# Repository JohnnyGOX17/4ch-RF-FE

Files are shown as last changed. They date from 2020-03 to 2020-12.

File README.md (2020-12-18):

# 4-Channel RF Front End

An open-source (KiCAD) RF front end with 4 independent RX &amp; TX channels optimized for MIMO/Radar prototyping. It implements an I2C bus for digital control of each channel’s attenuation and single-ended control of T/R switch for fast action. A switch-mode power supply and separate low dropout regulators for each channel are utilized to provide low-ripple power to RF Low Noise Amplifiers.

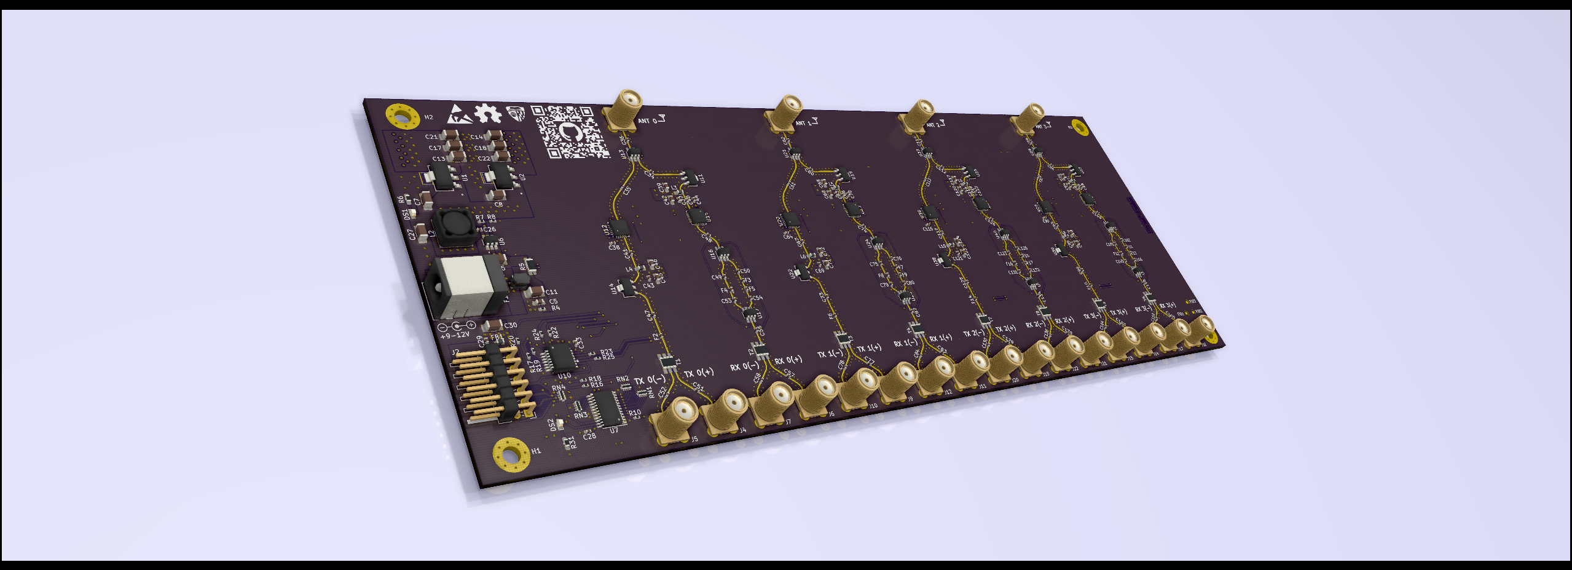
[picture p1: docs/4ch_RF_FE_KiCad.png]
kicad 3D


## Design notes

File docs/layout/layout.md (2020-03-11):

# Layout Notes

## [OSH-Park 4-Layer Prototype Service](https://docs.oshpark.com/services/four-layer/)

### Logistics

* Nominally shipped within 12 days of ordering
* >100 square inches of board space can be done with [Medium Run Service](https://docs.oshpark.com/services/four-layer-medium-run/)

### [KiCad Layout Settings](https://docs.oshpark.com/design-tools/kicad/kicad-design-rules/)

* Use Imperial (mils) units when inputting
* `Solder Mask Clearance` = 2 mil
* `Solder Mask Min Width` = 4 mil
* Disable both `blind/buried vias` and `micro vias`
* `Min track width` = 5 mil
* `Min track clearance` = 5 mil
* `Min via drill diameter` = 10 mil
* `Min via diameter` = 18 mil
  + Calculated as `(min drill diameter) + (annular ring spec)*2`
  + `Minimum Annular Ring` = 4 mil

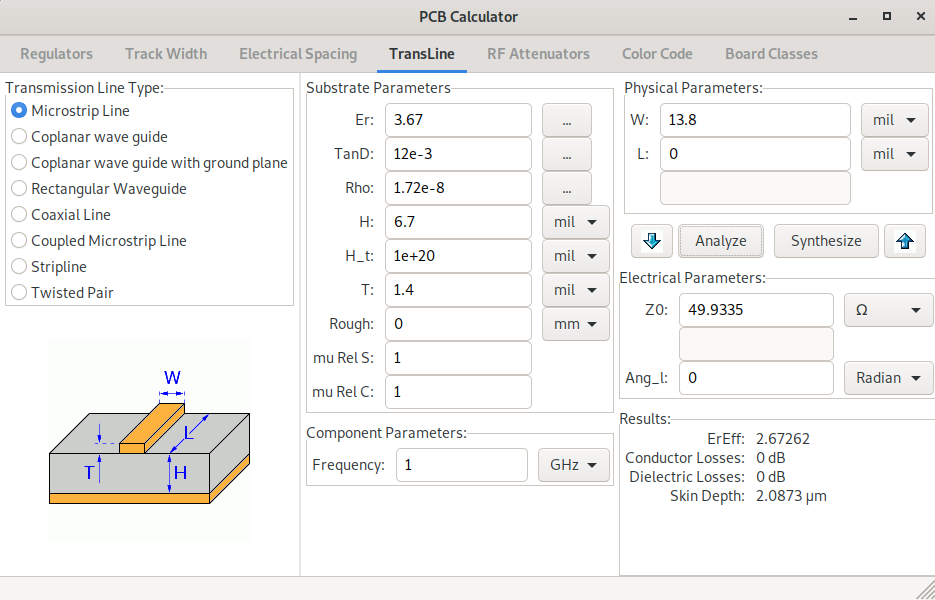
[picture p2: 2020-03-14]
docs/layout/50Ohm_SE_microstrip.png

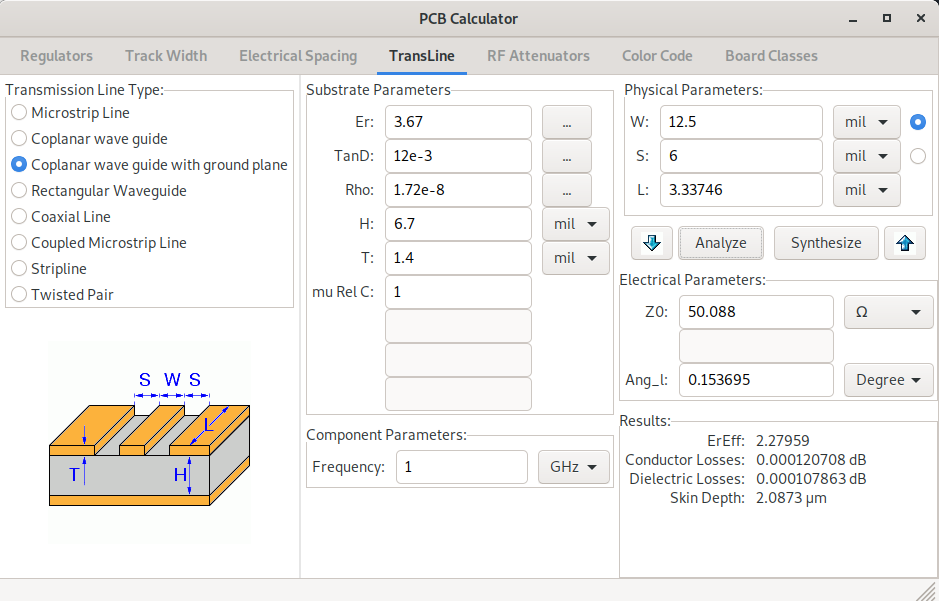
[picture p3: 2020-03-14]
docs/layout/50Ohm_CPWG_GND_plane.png

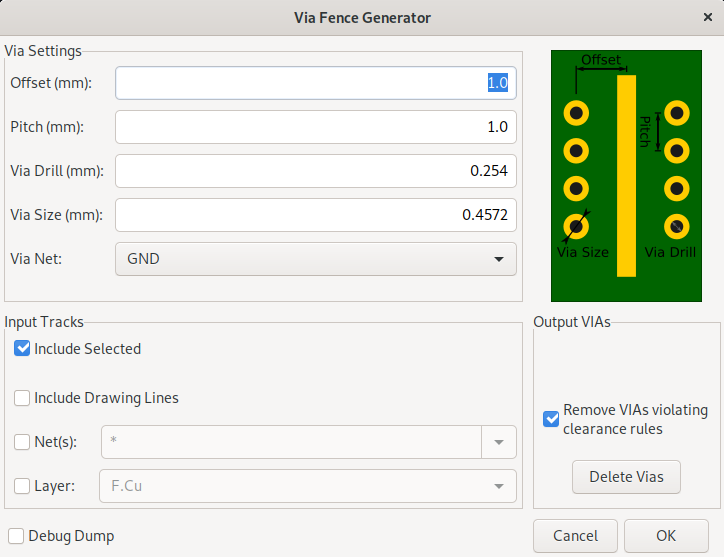
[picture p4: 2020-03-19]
docs/layout/CPWG_via_stitching.png

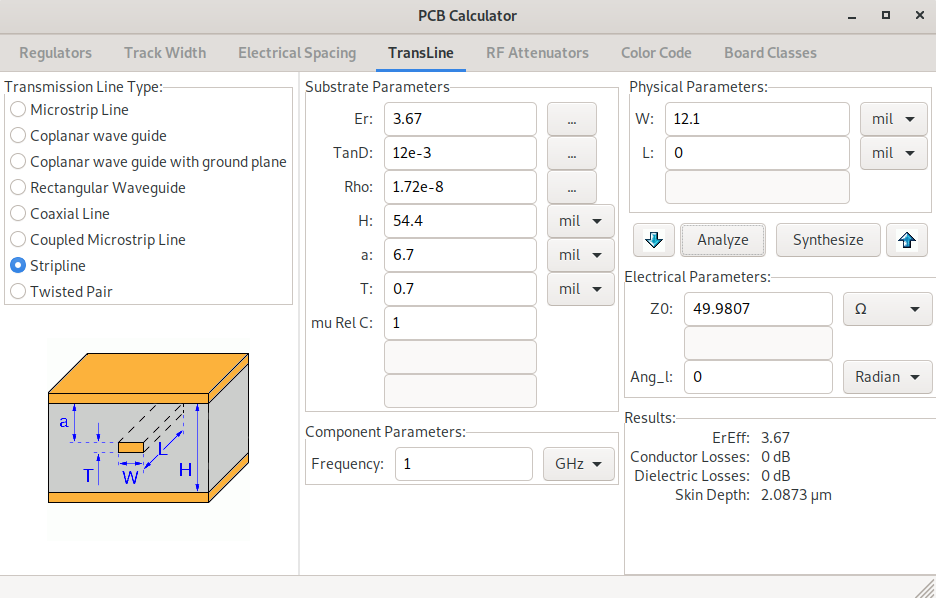
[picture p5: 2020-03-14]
docs/layout/50Ohm_SE_Stripline.png

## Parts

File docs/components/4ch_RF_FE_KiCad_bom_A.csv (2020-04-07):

Component | Description | Part | References | Value | Footprint | Quantity Per PCB | Datasheet | Digi-Key PN | Category | DK_Datasheet_Link | DK_Detail_Page | Family | MPN | Manufacturer | Status
1 | Unpolarized capacitor | C | C1 C4 C12 C26 C28 C29 C31 C32 C33 C38 C44 C55 C59 C64 C70 C81 C85 C90 C96 C107 C111 C116 C122 C133 C137 | 0.1µF | C_0402_1005Metric | 25 | https://search.murata.co.jp/Ceramy/image/img/A01X/G101/ENG/GRM155R71H104KE14-01.pdf | 490-13342-1-ND
2 | Unpolarized capacitor | C | C39 C45 C65 C71 C91 C97 C117 C123 | 1.2nF | C_0603_1608Metric_Pad1.05x0.95mm_HandSolder | 8 | https://api.kemet.com/component-edge/download/datasheet/C0603C122K5RACTU.pdf | 399-7851-1-ND
3 | Unpolarized capacitor | C | C7 C8 C9 C10 C11 C13 C14 C15 C16 C17 C18 C19 C20 C21 C22 C23 C24 C25 C30 | 10µF | C_1206_3216Metric_Pad1.42x1.75mm_HandSolder | 19 | http://www.samsungsem.com/kr/support/product-search/mlcc/CL31B106KAHNNNE.jsp | 1276-1804-1-ND
4 | Unpolarized capacitor | C | C3 C5 C6 C42 C46 C68 C72 C94 C98 C120 C124 | 1µF | C_0603_1608Metric_Pad1.05x0.95mm_HandSolder | 11 | http://www.samsungsem.com/kr/support/product-search/mlcc/CL10B105KA8NFNC.jsp | 1276-1942-1-ND
5 | Unpolarized capacitor | C | C27 | 22µF | C_1206_3216Metric_Pad1.42x1.75mm_HandSolder | 1 | http://www.samsungsem.com/kr/support/product-search/mlcc/CL31B226KQHNNNE.jsp | 1276-3146-1-ND
6 | Unpolarized capacitor | C | C34 C35 C36 C40 C41 C47 C48 C49 C50 C51 C52 C53 C54 C56 C57 C58 C60 C61 C62 C66 C67 C73 C74 C75 C76 C77 C78 C79 C80 C82 C83 C84 C86 C87 C88 C92 C93 C99 C100 C101 C102 C103 C104 C105 C106 C108 C109 C110 C112 C113 C114 C118 C119 C125 C126 C127 C128 C129 C130 C131 C132 C134 C135 C136 | 330pF | C_0402_1005Metric | 64 | https://api.kemet.com/component-edge/download/datasheet/C0402C331J5GACTU.pdf | 399-7787-1-ND
7 | Unpolarized capacitor | C | C37 C43 C63 C69 C89 C95 C115 C121 | 68pF | C_0402_1005Metric | 8 | https://api.kemet.com/component-edge/download/datasheet/C0402C680K5RAC7867.pdf | 399-19382-1-ND
8 | LED GREEN CLEAR CHIP SMD | LTST-C190KGKT | DS1 DS2 | LTST-C190KGKT | LED_0603 | 2 | http://optoelectronics.liteon.com/upload/download/DS22-2000-074/LTST-C190KGKT.PDF | 160-1435-1-ND | Optoelectronics | http://optoelectronics.liteon.com/upload/download/DS22-2000-074/LTST-C190KGKT.PDF | /product-detail/en/lite-on-inc/LTST-C190KGKT/160-1435-1-ND/386814 | LED Indication - Discrete | LTST-C190KGKT | Lite-On Inc. | Active
9 | RF FILTER HIGH PASS 2.4GHZ 0603 | DEA162300HT-8047A1 | F5 F9 F13 F17 | DEA162300HT-8047A1 | F_DEA16_LGA | 4 | https://media.digikey.com/pdf/Data%20Sheets/TDK%20PDFs/DEA162300HT-8047A1_Rev1_0.pdf | 445-175383-1-ND |  |  |  |  |  | TDK
10 | FUSE BOARD MOUNT 5A 32VDC 0603 | ERB-RE5R00V | F1 | ERB-RE5R00V | 603 | 1 | https://industrial.panasonic.com/cdbs/www-data/pdf/AFA0000/AFA0000C7.pdf | P15125CT-ND | Circuit Protection |  |  | Fuses |  | Panasonic | Active
11 | DC to 2.14 GHz 50 Ohm Low Pass Filter | LP0603A2140ANTR | F4 F8 F12 F16 | LP0603A2140ANTR | F_0603_2x2_LGA | 4 | http://datasheets.avx.com/lp0603.pdf | 478-2914-1-ND |  |  |  |  |  | AVX
12 | DC to 3600 MHz 50 Ohm Low Pass Filter | LPF04023600L | F2 F3 F6 F7 F10 F11 F14 F15 | LPF04023600L | F_0402_1005Metric_2x2_LGA | 8 | https://media.digikey.com/pdf/Data%20Sheets/American%20Technical%20Ceramics/0402_LPF_Series_DS.pdf | 1284-1984-1-ND |  |  |  |  |  | ATC
13 | FERRITE BEAD 1.5 KOHM 0603 1LN | BLM18HE152SN1D | FB1 | BLM18HE152SN1D | 603 | 1 | https://www.murata.com/en-us/products/productdata/8796741599262/ENFA0004.pdf | 490-5216-1-ND | Filters | https://www.murata.com/en-us/products/productdata/8796741599262/ENFA0004.pdf | /product-detail/en/murata-electronics-north-america/BLM18HE152SN1D/490-5216-1-ND/1948392 | Ferrite Beads and Chips | BLM18HE152SN1D | Murata Electronics North America | Active
14 | CONN SMA JACK STR 50 OHM PCB | 5-1814832-1 | J3 J4 J5 J6 J7 J8 J9 J10 J11 J12 J13 J14 J15 J16 J17 J18 J19 J20 J21 J22 | 5-1814832-1 | RF_SMA_Vertical_5-1814832-1 | 20 | https://www.te.com/commerce/DocumentDelivery/DDEController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 | A97594-ND | Connectors, Interconnects | https://www.te.com/commerce/DocumentDelivery/DDEController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 | /product-detail/en/te-connectivity-amp-connectors/5-1814832-1/A97594-ND/1755982 | Coaxial Connectors (RF) | 5-1814832-1 | TE Connectivity AMP Connectors | Active
15 | CONN PWR JACK 1.75X4.75MM SOLDER | PJ1-021-SMT-TR | J1 | PJ1-021-SMT-TR | CUI_PJ1-021-SMT-TR | 1 | https://www.cuidevices.com/product/resource/pj1-021-smt-tr.pdf | CP1-021PJCT-ND
16 | CONN HDR 12POS 0.1 TIN PCB R/A | PPTC062LJBN-RC | J2 | PPTC062LJBN-RC | PinHeader_2x06_P2.54mm_Horizontal | 1 | https://media.digikey.com/pdf/Data%20Sheets/Sullins%20PDFs/Female_Headers.100_DS.pdf | S5520-ND | Connectors, Interconnects |  |  | Rectangular Connectors - Headers, Female Pins |  | Sullins Connector Solutions | Active
17 | Inductor | L | L3 L4 L5 L6 L7 L8 L9 L10 | 43nH | L_0603_1608Metric_Pad1.05x0.95mm_HandSolder | 8 | https://search.murata.co.jp/Ceramy/image/img/P02/JELF243A-0024.pdf | 490-6892-1-ND
18 | CMC 500 Ohms @ 100MHz 2A DCR 40 mOhm | ACP3225 | L1 | ACP3225 | CMC_3225_2x2_LGA | 1 | https://product.tdk.com/info/en/catalog/datasheets/cmf_commercial_power_acp3225_en.pdf | 445-172408-1-ND
19 | FIXED IND 3.3UH 3.5A 20 MOHM SMD | SRR6038-3R3Y | L2 | SRR6038-3R3Y | SRR6038-3R3Y | 1 | https://www.bourns.com/docs/Product-Datasheets/SRR6038.pdf | SRR6038-3R3YCT-ND
20 | Resistor, US symbol | R_US | R2 R3 | 10 | R_0402_1005Metric | 2 | https://www.yageo.com/upload/media/product/productsearch/datasheet/rchip/PYu-RC_Group_51_RoHS_L_10.pdf | 311-10.0LRCT-ND
21 | Resistor, US symbol | R_US | R23 R25 | 100 | R_0402_1005Metric | 2 | https://www.yageo.com/upload/media/product/productsearch/datasheet/rchip/PYu-RC_Group_51_RoHS_L_10.pdf | 311-100LRCT-ND
22 | Resistor, US symbol | R_US | R4 | 100k | R_0402_1005Metric | 1 | https://www.yageo.com/upload/media/product/productsearch/datasheet/rchip/PYu-RC_Group_51_RoHS_L_10.pdf | 311-100KLRCT-ND
23 | Resistor, US symbol | R_US | R8 R10 R11 R12 R14 R26 R27 R28 R29 R30 | 10k | R_0402_1005Metric | 10 | https://www.yageo.com/upload/media/product/productsearch/datasheet/rchip/PYu-RC_Group_51_RoHS_L_10.pdf | 311-10.0KLRCT-ND
24 | Resistor, US symbol | R_US | R6 | 180 | R_0603_1608Metric_Pad1.05x0.95mm_HandSolder | 1 | https://www.yageo.com/upload/media/product/productsearch/datasheet/rchip/PYu-RC_Group_51_RoHS_L_10.pdf | 311-180GRCT-ND
25 | Resistor, US symbol | R_US | R16 R17 R18 R19 R20 R21 R22 R24 | 33 | R_0402_1005Metric | 8 | https://www.yageo.com/upload/media/product/productsearch/datasheet/rchip/PYu-RC_Group_51_RoHS_L_10.pdf | 311-33.0LRCT-ND
26 | Resistor, US symbol | R_US | R7 | 61.9k | R_0402_1005Metric | 1 | https://www.yageo.com/upload/media/product/productsearch/datasheet/rchip/PYu-RC_Group_51_RoHS_L_10.pdf | 311-61.9KLRCT-ND
27 | Resistor, US symbol | R_US | R31 | 75 | R_0603_1608Metric_Pad1.05x0.95mm_HandSolder | 1 | https://www.yageo.com/upload/media/product/productsearch/datasheet/rchip/PYu-RC_Group_51_RoHS_L_10.pdf | 311-75.0HRCT-ND
28 | RES 0.002 OHM 1% 1W 1206 | CSR1206-0R002F1 | R5 | CSR1206-0R002F1 | CSR_4pin_1206_3216Metric_Pad1.42x1.75mm_HandSolder | 1 | https://riedon.com/media/pdf/CSR.pdf | 696-1370-1-ND
29 | 4 resistor network, parallel topology, DIP package | R_Pack04 | RN1 RN2 RN3 RN4 | EXB-28V103JX | R_Array_Convex_4x0402 | 4 | https://industrial.panasonic.com/cdbs/www-data/pdf/AOC0000/AOC0000C14.pdf | Y7103CT-ND
30 | 1:1 Transformer Balun 5 - 8000 MHz | MABA-011082 | T1 T2 T3 T4 T5 T6 T7 T8 | MABA-011082 | T_6pin_23_balun | 8 | https://cdn.macom.com/datasheets/MABA-011082.pdf | 1465-1843-1-ND
31 | IC AMP W-CDMA 30MHZ-6GHZ SOT89-3 | ADL5611ARKZ-R7 | U11 U14 U19 U22 U27 U30 U35 U38 | ADL5611ARKZ-R7 | ADL5611ARKZ-R7 | 8 | https://www.analog.com/media/en/technical-documentation/data-sheets/ADL5611.pdf | ADL5611ARKZ-R7CT-ND
32 | IC RF SWITCH SPDT 4GHZ SOT26 | HMC544AETR | U13 U16 U17 U21 U24 U25 U29 U32 U33 U37 U40 U41 | HMC544AETR | SOT-23-6_Handsoldering | 12 | https://www.analog.com/media/en/technical-documentation/data-sheets/hmc544ae.pdf | 1127-1856-1-ND
33 | IC CURRENT MONITOR 1% SOT23-8 | INA219AIDCNR | U5 | INA219AIDCNR | SOT-23-8 | 1 | http://www.ti.com/general/docs/suppproductinfo.tsp?distId=10 | 296-23770-1-ND | Integrated Circuits (ICs) | http://www.ti.com/general/docs/suppproductinfo.tsp?distId=10 | /product-detail/en/texas-instruments/INA219AIDCNR/296-23770-1-ND/1952550 | PMIC - Current Regulation/Management | INA219AIDCNR | Texas Instruments | Active
34 | 2Kb (256x8) I2C Serial EEPROM, 1.6-5.5V, TSSOP-8 | M24C02-FDW | U8 | M24C02-FDW | TSSOP-8_4.4x3mm_P0.65mm | 1 | http://www.st.com/content/ccc/resource/technical/document/datasheet/b0/d8/50/40/5a/85/49/6f/DM00071904.pdf/files/DM00071904.pdf/jcr:content/translations/en.DM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 | 497-15746-1-ND
35 | IC REG LINEAR 5V 300MA SOT223-3 | MCP1755ST-5002E_DB | U1 U2 U3 U4 | MCP1755ST-5002E_DB | MCP1755ST-5002E_DB | 4 | http://www.microchip.com/mymicrochip/filehandler.aspx?ddocname=en560605 | MCP1755ST-5002E/DBCT-ND
36 | Low voltage 8-channel I2C switch with reset, TSSOP-24 | PCA9548APW | U7 | PCA9548APW | TSSOP-24_4.4x7.8mm_P0.65mm | 1 | http://www.ti.com/lit/ds/symlink/pca9548a.pdf | 296-21775-1-ND
37 | IC I/O EXPANDER 16BIT 24TSSOP | PCAL6416APW | U18 U26 U34 U42 | PCAL6416APW | TSSOP-24_W4.40mm | 4 | https://www.nxp.com/docs/en/data-sheet/PCAL6416A.pdf | 568-9922-1-ND
38 | RF ATTENUATOR 31.5DB 50OHM 24QFN | PE43711 | U12 U15 U20 U23 U28 U31 U36 U39 | PE43711 | QFN-24-1EP_4x4mm_P0.5mm_EP2.7x2.7mm | 8 | http://www.psemi.com/pdf/datasheets/pe43711ds.pdf | 1046-1138-1-ND
39 | IC INVERTER 6CH 6-INP 14TSSOP | SN74HCU04PWR | U10 | SN74HCU04PWR | SN74HCU04PWR | 1 | http://www.ti.com/lit/ds/symlink/sn74hcu04.pdf | 296-9821-1-ND
40 | IC BUF NON-INVERT 3.6V 14TSSOP | SN74LVC125APWR | U9 | SN74LVC125APWR | SN74LVC125APWR | 1 | http://www.ti.com/lit/ds/symlink/sn74lvc125a.pdf | 296-1222-1-ND
41 | IC REG BUCK ADJ 2A TSOT23-6 | TPS562208DDCT | U6 | TPS562208DDCT | TPS562208DDCT | 1 | http://www.ti.com/lit/ds/symlink/tps562208.pdf | 296-43806-1-ND
Component Groups: | 44
Component Count: | 275
Fitted Components: | 269
Number of PCBs: | 1
Total components: | 269
Schematic Version: | A
Schematic Date: | 2020-03-08
PCB Variant: | default
BoM Date: | Sat 21 Mar 2020 07:16:21 PM EDT
Schematic Source: | 4ch_RF_FE_KiCad.sch
KiCad Version: | Eeschema 5.1.5-1.fc31

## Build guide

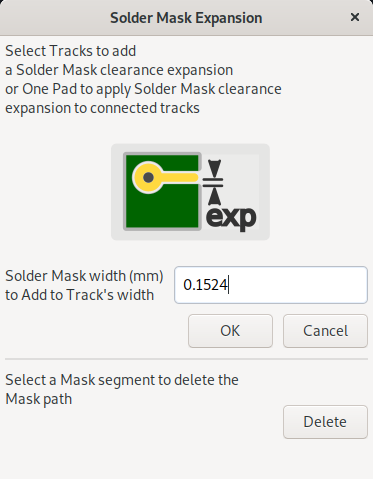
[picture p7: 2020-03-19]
docs/layout/6mil_soldermask_expander.png

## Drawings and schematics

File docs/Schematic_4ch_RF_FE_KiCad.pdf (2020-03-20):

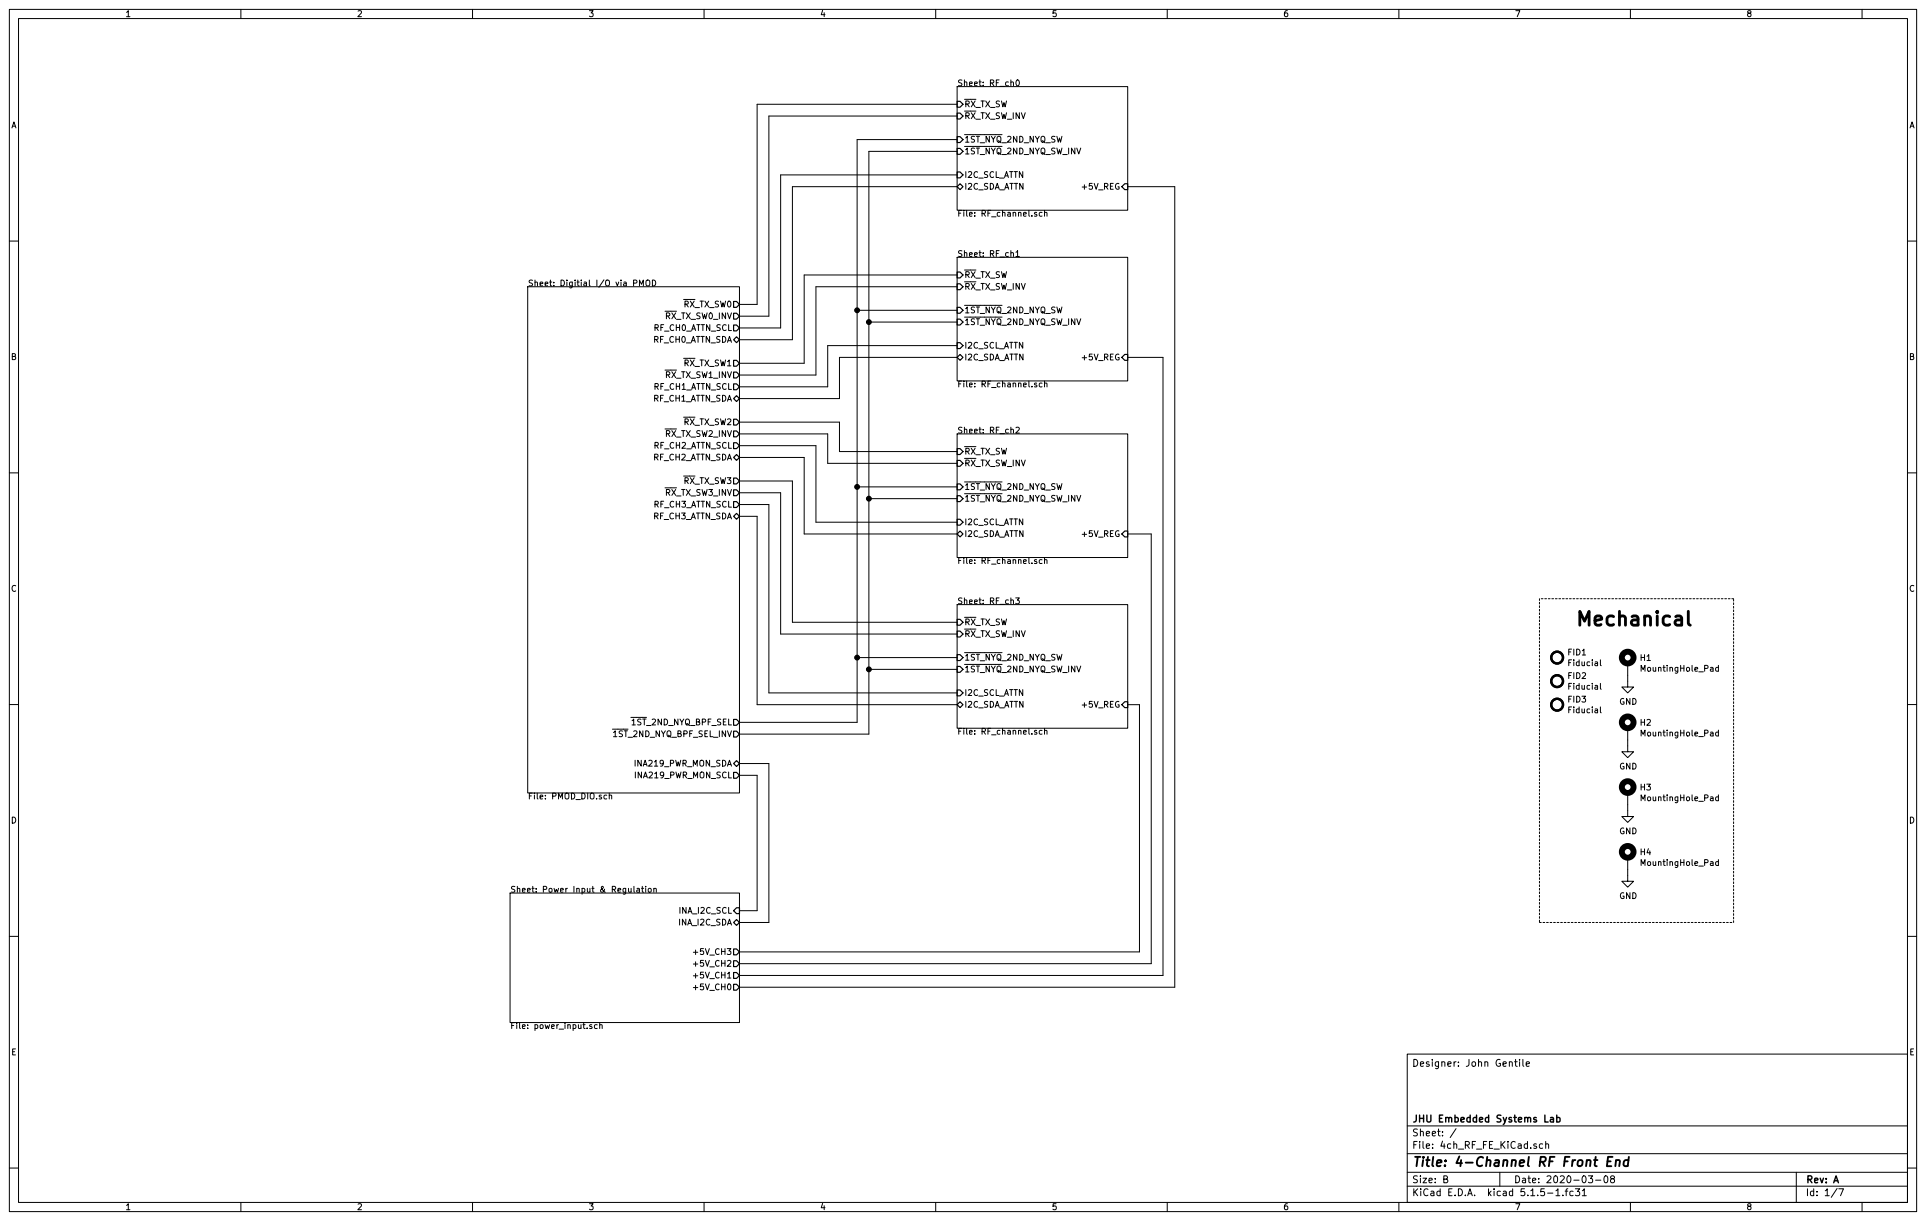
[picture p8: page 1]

Sheet: Digitial I/O via PMOD

Sheet: Power Input & Regulation

File: 4ch_RF_FE_KiCad.sch Sheet: / JHU Embedded Systems Lab

Id: 1/7 Title: 4-Channel RF Front End

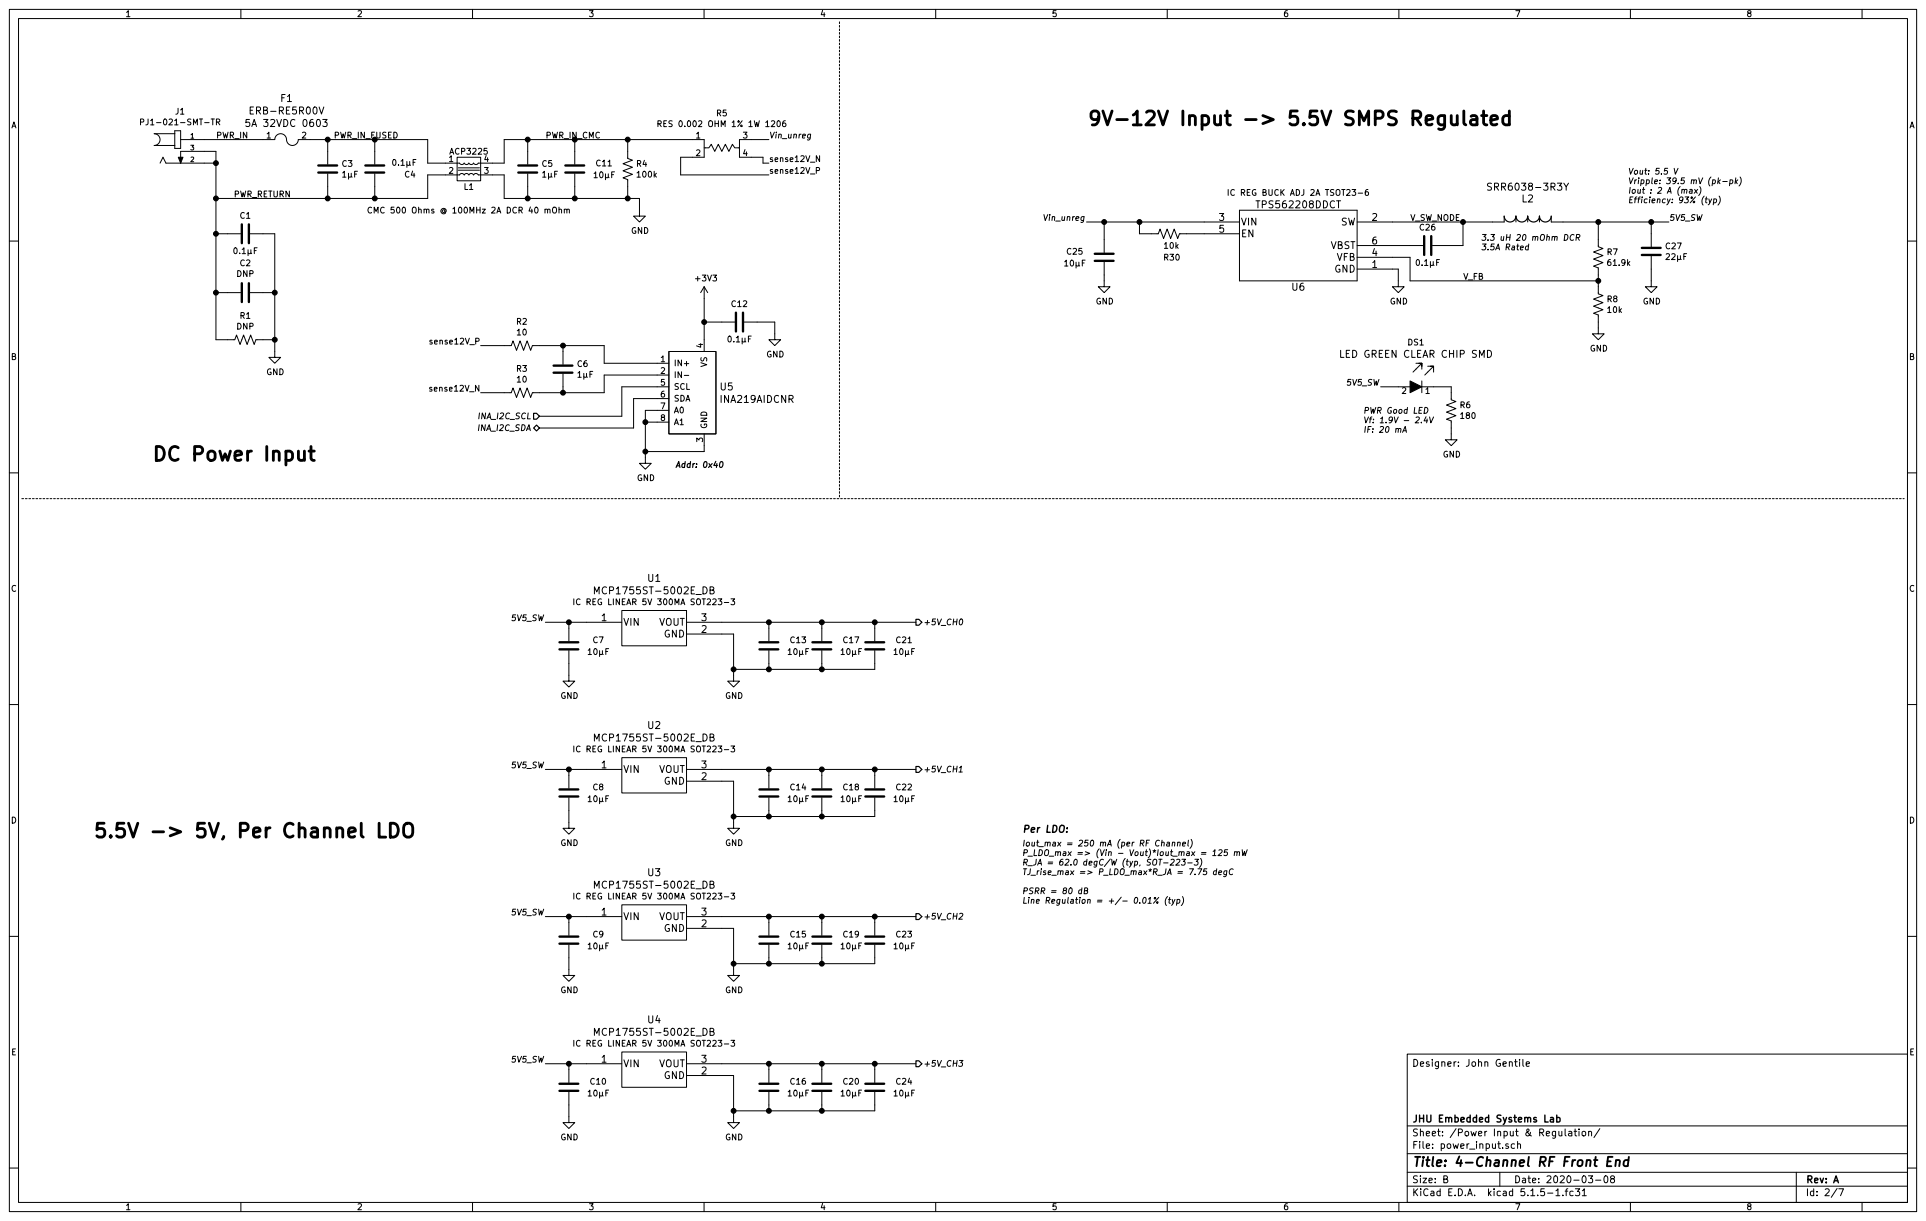
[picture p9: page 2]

IF: 20 mA 9V-12V Input -> 5.5V SMPS Regulated

L1 ACP3225 CMC 500 Ohms @ 100MHz 2A DCR 40 mOhm

Vout: 5.5 V
Vripple: 39.5 mV (pk-pk)
Iout : 2 A (max)
Efficiency: 93% (typ)

IC REG BUCK ADJ 2A TSOT23-6

3.5A Rated 5.5V -> 5V, Per Channel LDO

Iout_max = 250 mA (per RF Channel)
P_LDO_max => (Vin - Vout)*Iout_max = 125 mW
R_JA = 62.0 degC/W (typ, SOT-223-3)
TJ_rise_max => P_LDO_max*R_JA = 7.75 degC

JHU Embedded Systems Lab
Sheet: /Power Input & Regulation/
File: power_input.sch
Id: 2/7 Title: 4-Channel RF Front End

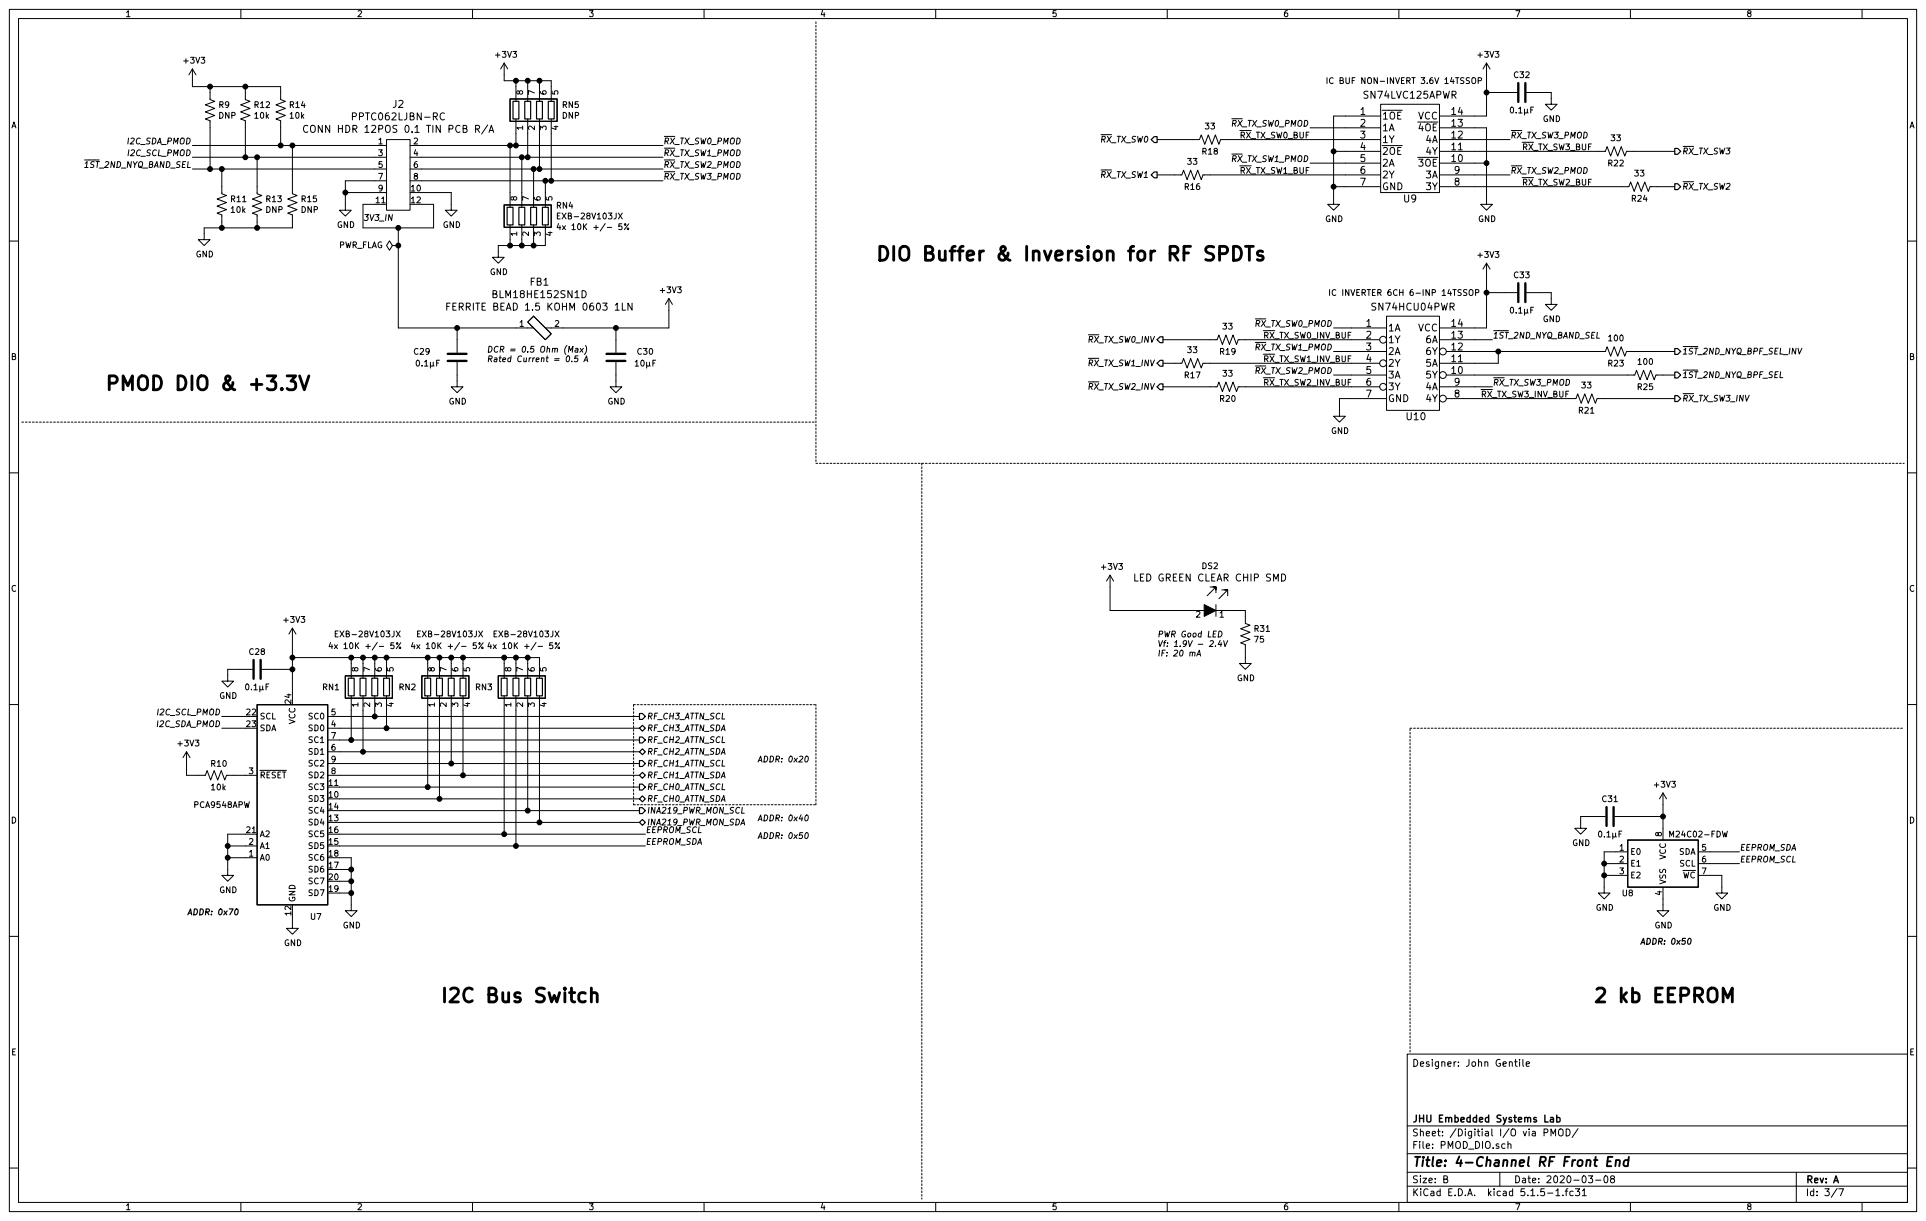
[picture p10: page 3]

CONN HDR 12POS 0.1 TIN PCB R/A

DCR = 0.5 Ohm (Max) Rated Current = 0.5 A

JHU Embedded Systems Lab
Sheet: /Digitial I/O via PMOD/
File: PMOD_DIO.sch
Id: 3/7 Title: 4-Channel RF Front End

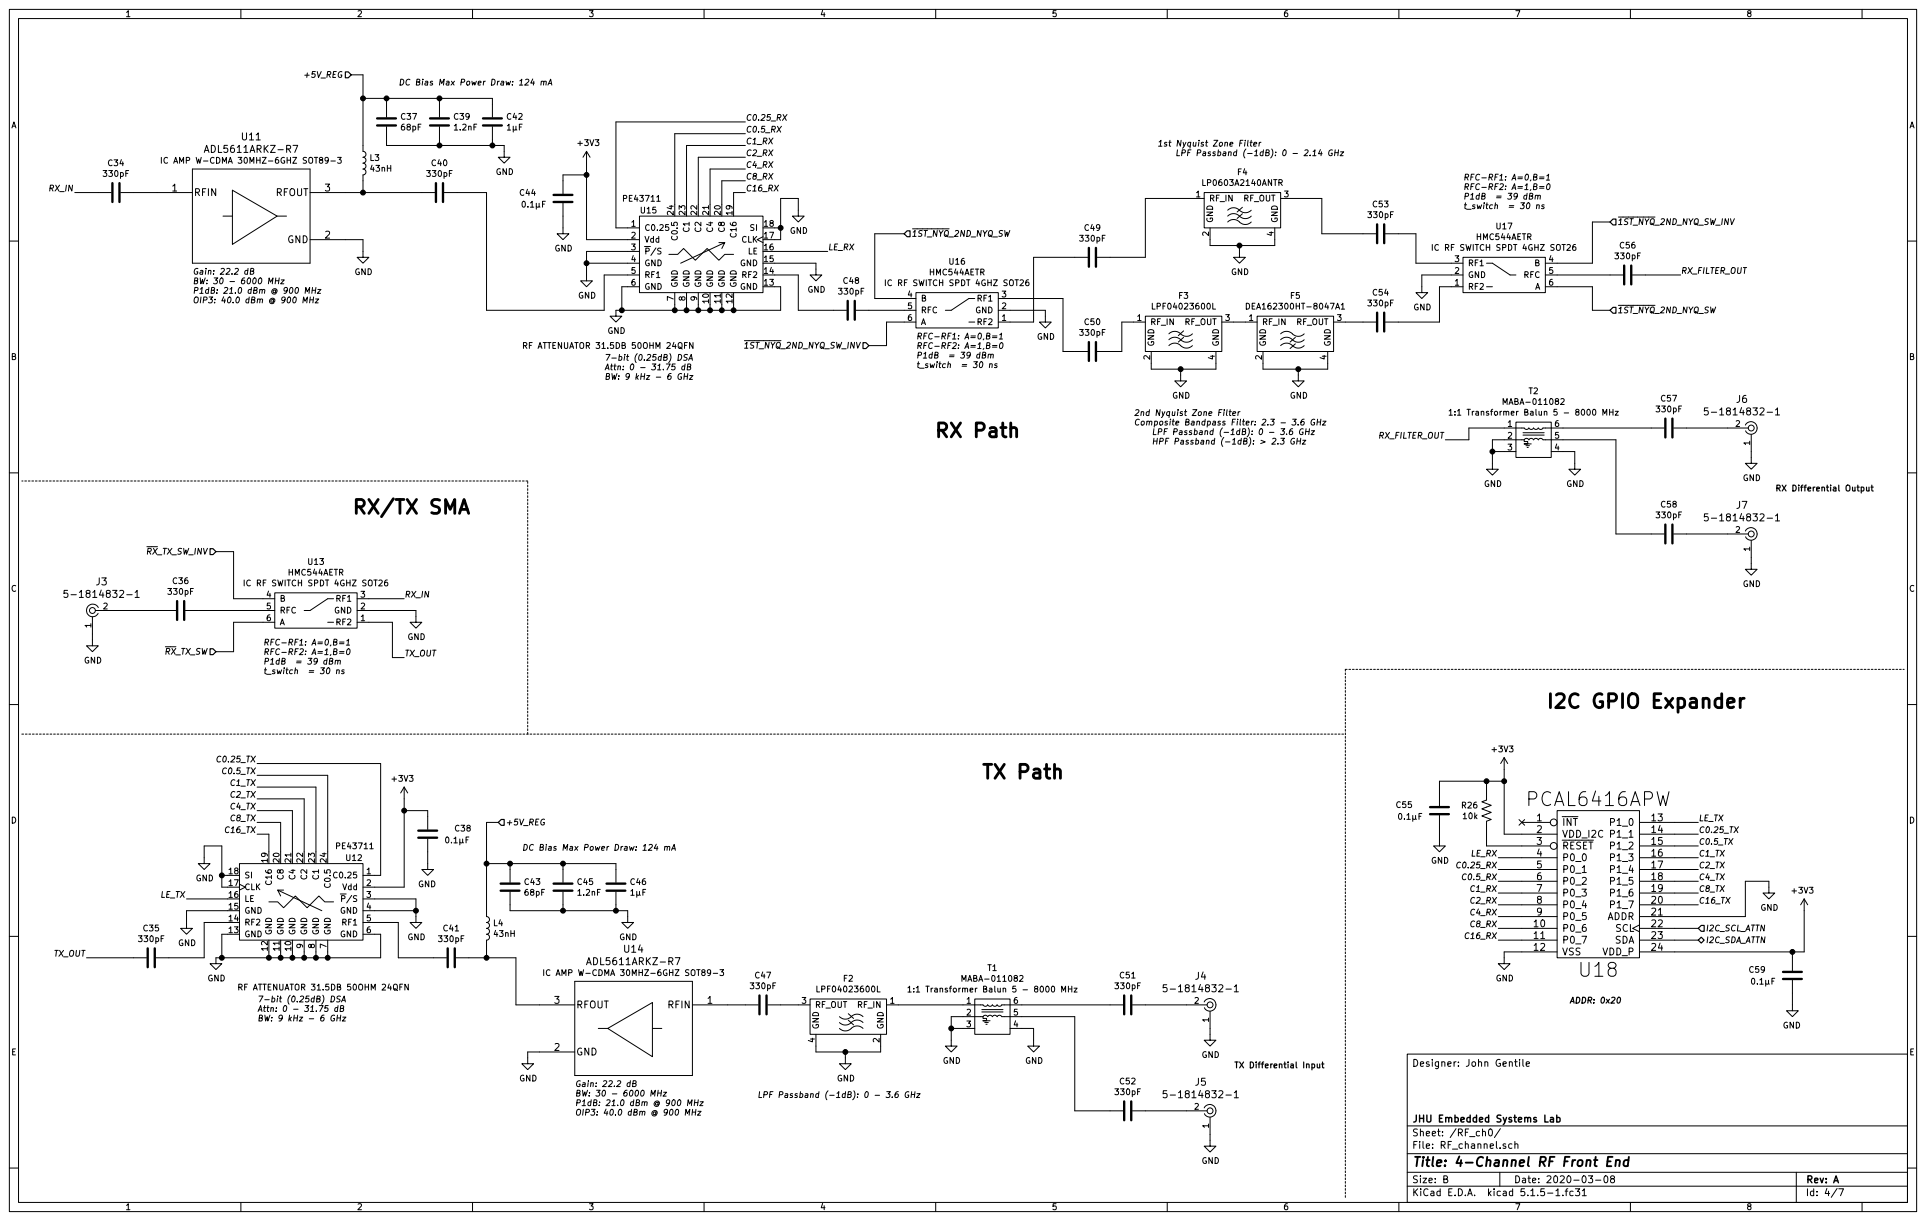
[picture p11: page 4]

LPF Passband (-1dB): 0 - 2.14 GHz Gain: 22.2 dB

t_switch = 30 ns 2nd Nyquist Zone Filter

t_switch = 30 ns RFC-RF1: A=0,B=1 RFC-RF2: A=1,B=0 P1dB = 39 dBm

1:1 Transformer Balun 5 - 8000 MHz GND

Composite Bandpass Filter: 2.3 - 3.6 GHz
LPF Passband (-1dB): 0 - 3.6 GHz

HPF Passband (-1dB): > 2.3 GHz Gain: 22.2 dB

IC RF SWITCH SPDT 4GHZ SOT26

Designer: John Gentile GND

JHU Embedded Systems Lab
Sheet: /RF_ch0/
File: RF_channel.sch
Id: 4/7 Title: 4-Channel RF Front End

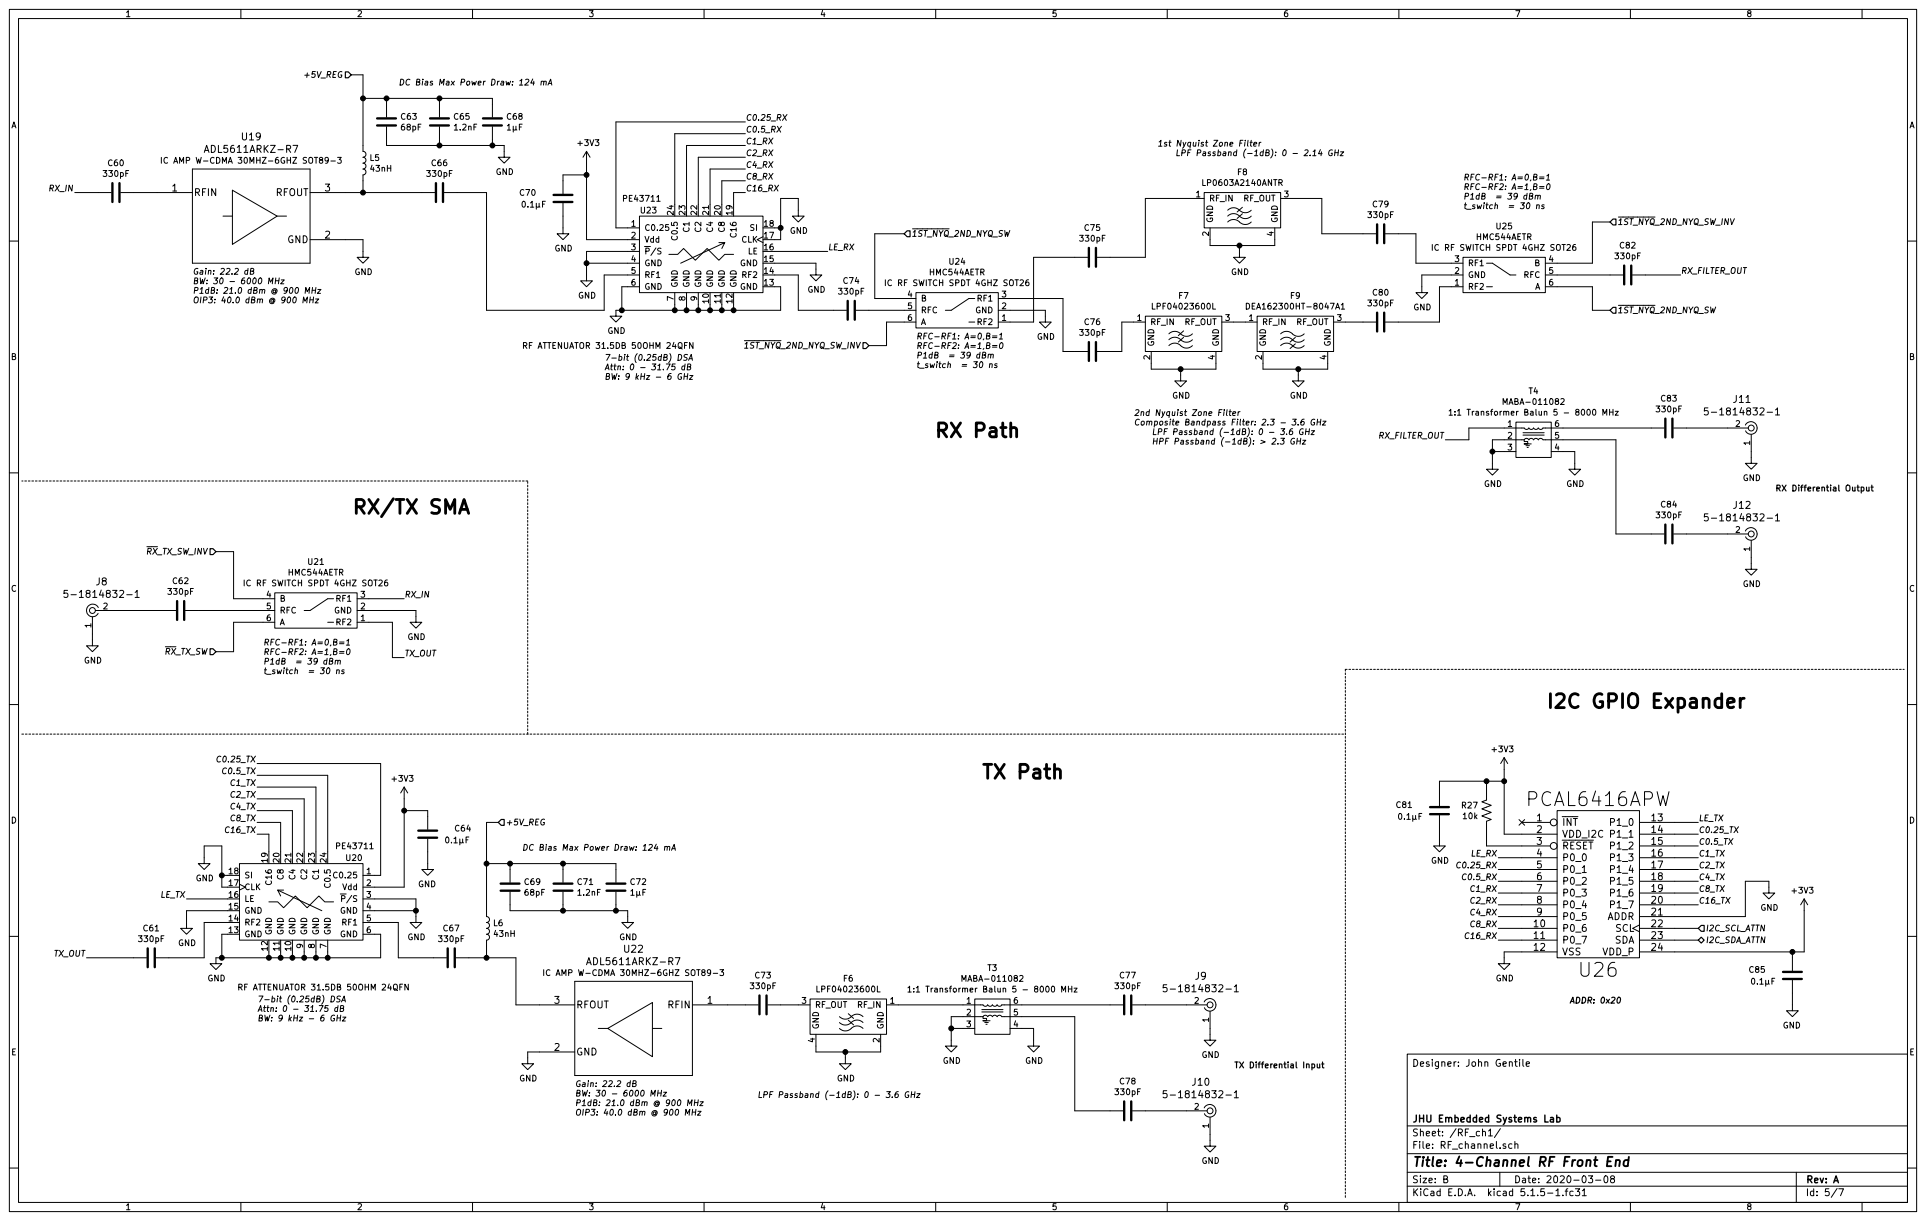
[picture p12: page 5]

LPF Passband (-1dB): 0 - 2.14 GHz Gain: 22.2 dB

t_switch = 30 ns 2nd Nyquist Zone Filter

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

1:1 Transformer Balun 5 - 8000 MHz GND

Composite Bandpass Filter: 2.3 - 3.6 GHz
LPF Passband (-1dB): 0 - 3.6 GHz

HPF Passband (-1dB): > 2.3 GHz Gain: 22.2 dB

IC RF SWITCH SPDT 4GHZ SOT26

JHU Embedded Systems Lab
Sheet: /RF_ch1/
File: RF_channel.sch
Id: 5/7 Title: 4-Channel RF Front End

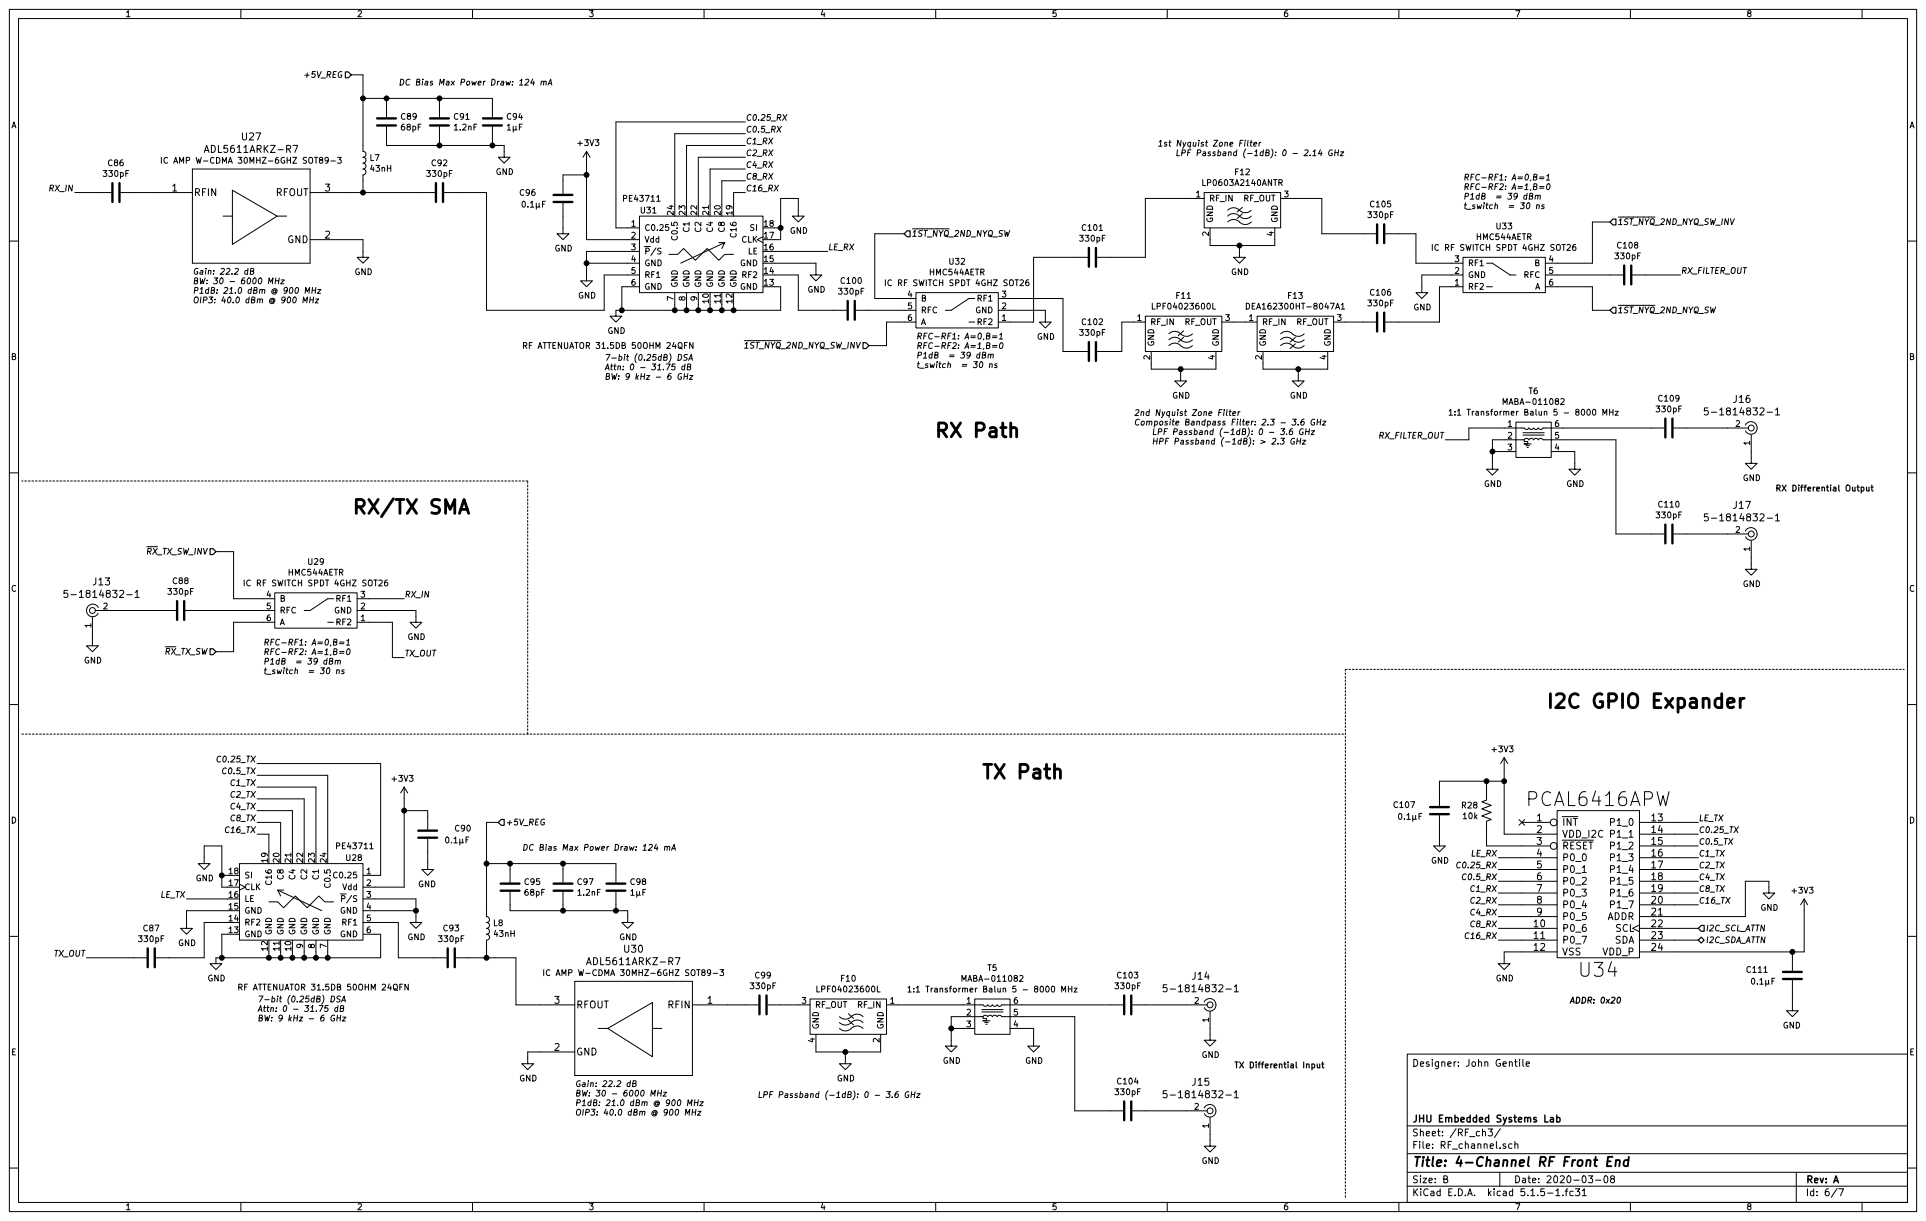
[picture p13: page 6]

LPF Passband (-1dB): 0 - 2.14 GHz Gain: 22.2 dB

t_switch = 30 ns 2nd Nyquist Zone Filter

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

1:1 Transformer Balun 5 - 8000 MHz GND

Composite Bandpass Filter: 2.3 - 3.6 GHz
LPF Passband (-1dB): 0 - 3.6 GHz

HPF Passband (-1dB): > 2.3 GHz Gain: 22.2 dB

IC RF SWITCH SPDT 4GHZ SOT26

JHU Embedded Systems Lab
Sheet: /RF_ch3/
File: RF_channel.sch
Id: 6/7 Title: 4-Channel RF Front End

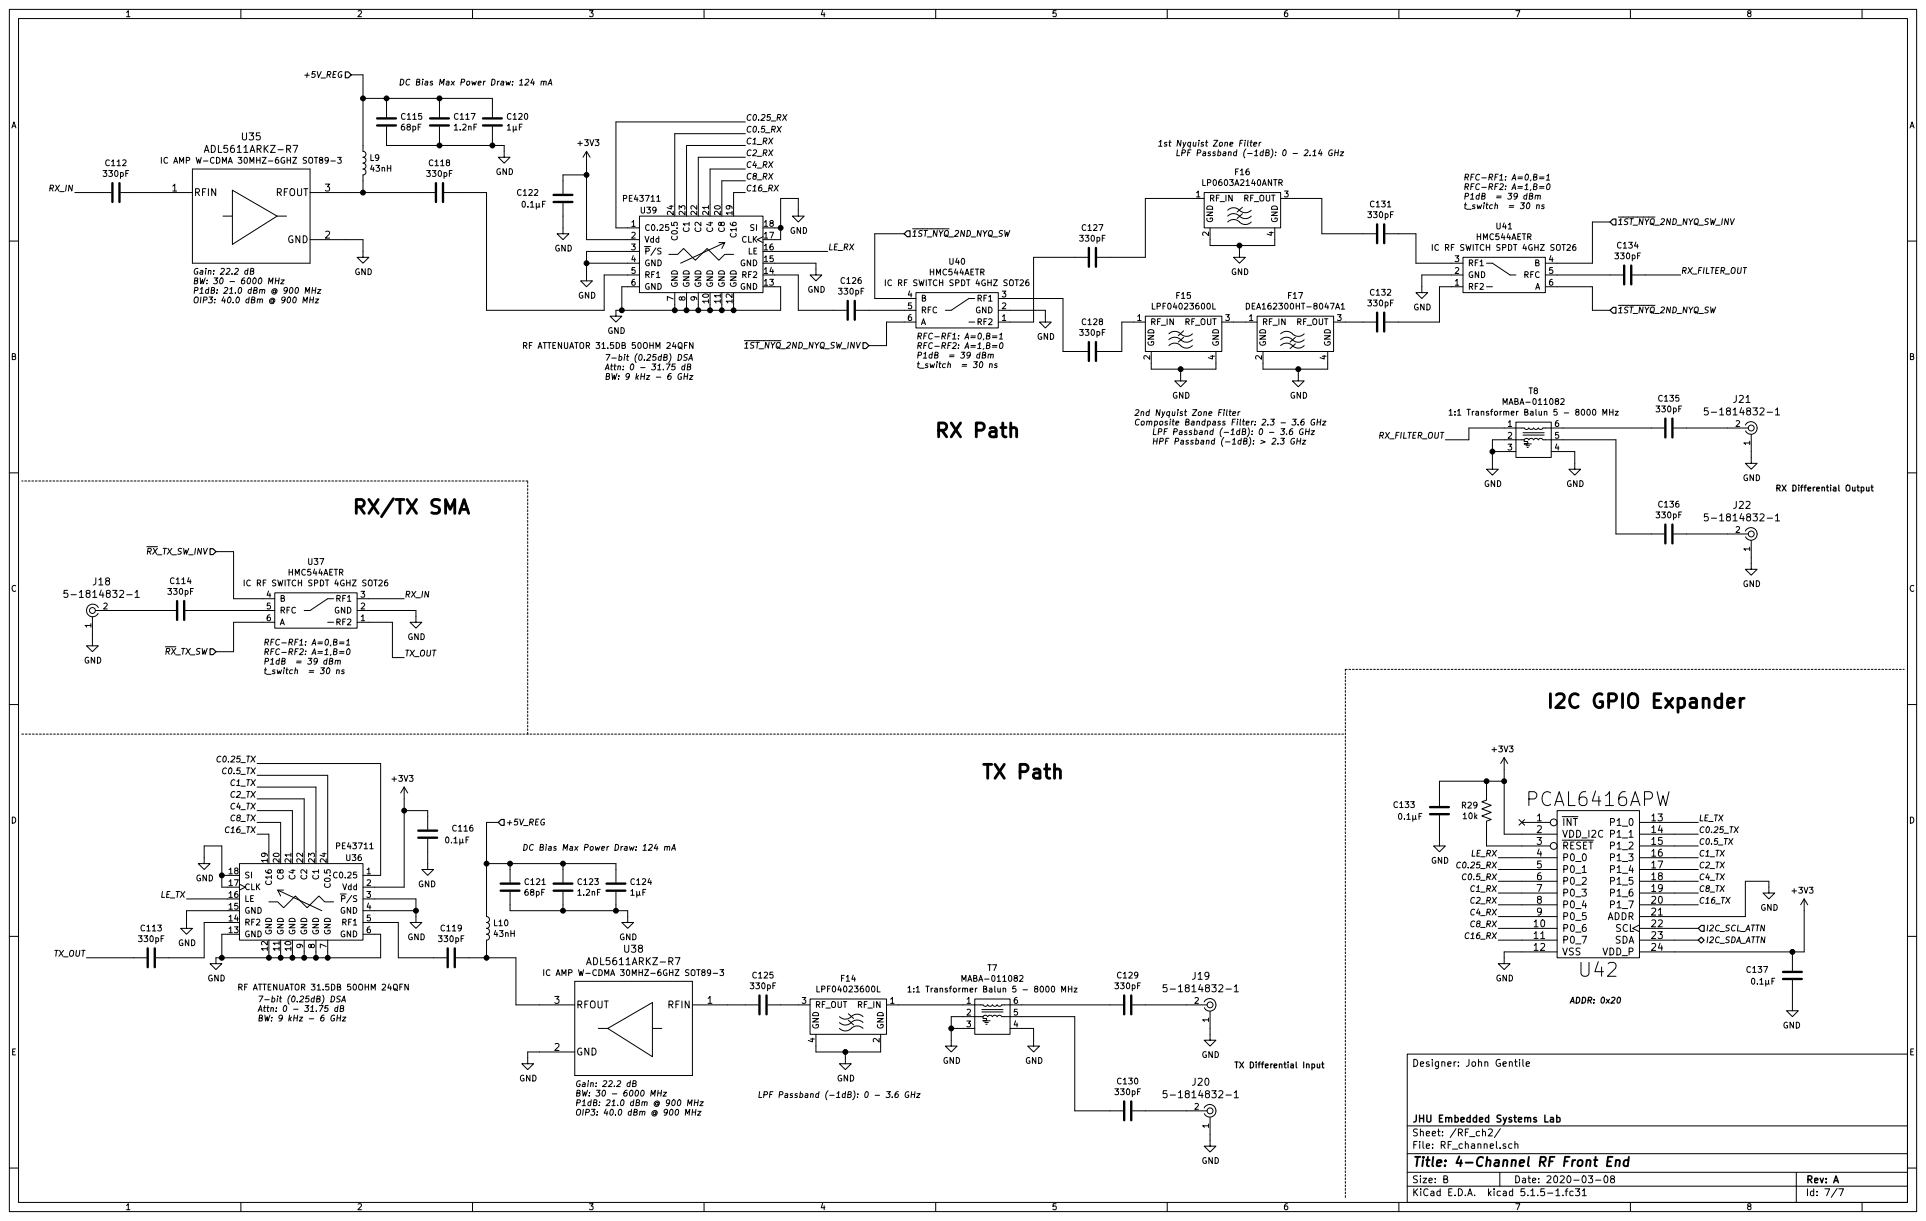
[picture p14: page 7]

LPF Passband (-1dB): 0 - 2.14 GHz Gain: 22.2 dB

t_switch = 30 ns 2nd Nyquist Zone Filter

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

1:1 Transformer Balun 5 - 8000 MHz GND

Composite Bandpass Filter: 2.3 - 3.6 GHz
LPF Passband (-1dB): 0 - 3.6 GHz

HPF Passband (-1dB): > 2.3 GHz Gain: 22.2 dB

IC RF SWITCH SPDT 4GHZ SOT26

JHU Embedded Systems Lab
Sheet: /RF_ch2/
File: RF_channel.sch
Id: 7/7 Title: 4-Channel RF Front End

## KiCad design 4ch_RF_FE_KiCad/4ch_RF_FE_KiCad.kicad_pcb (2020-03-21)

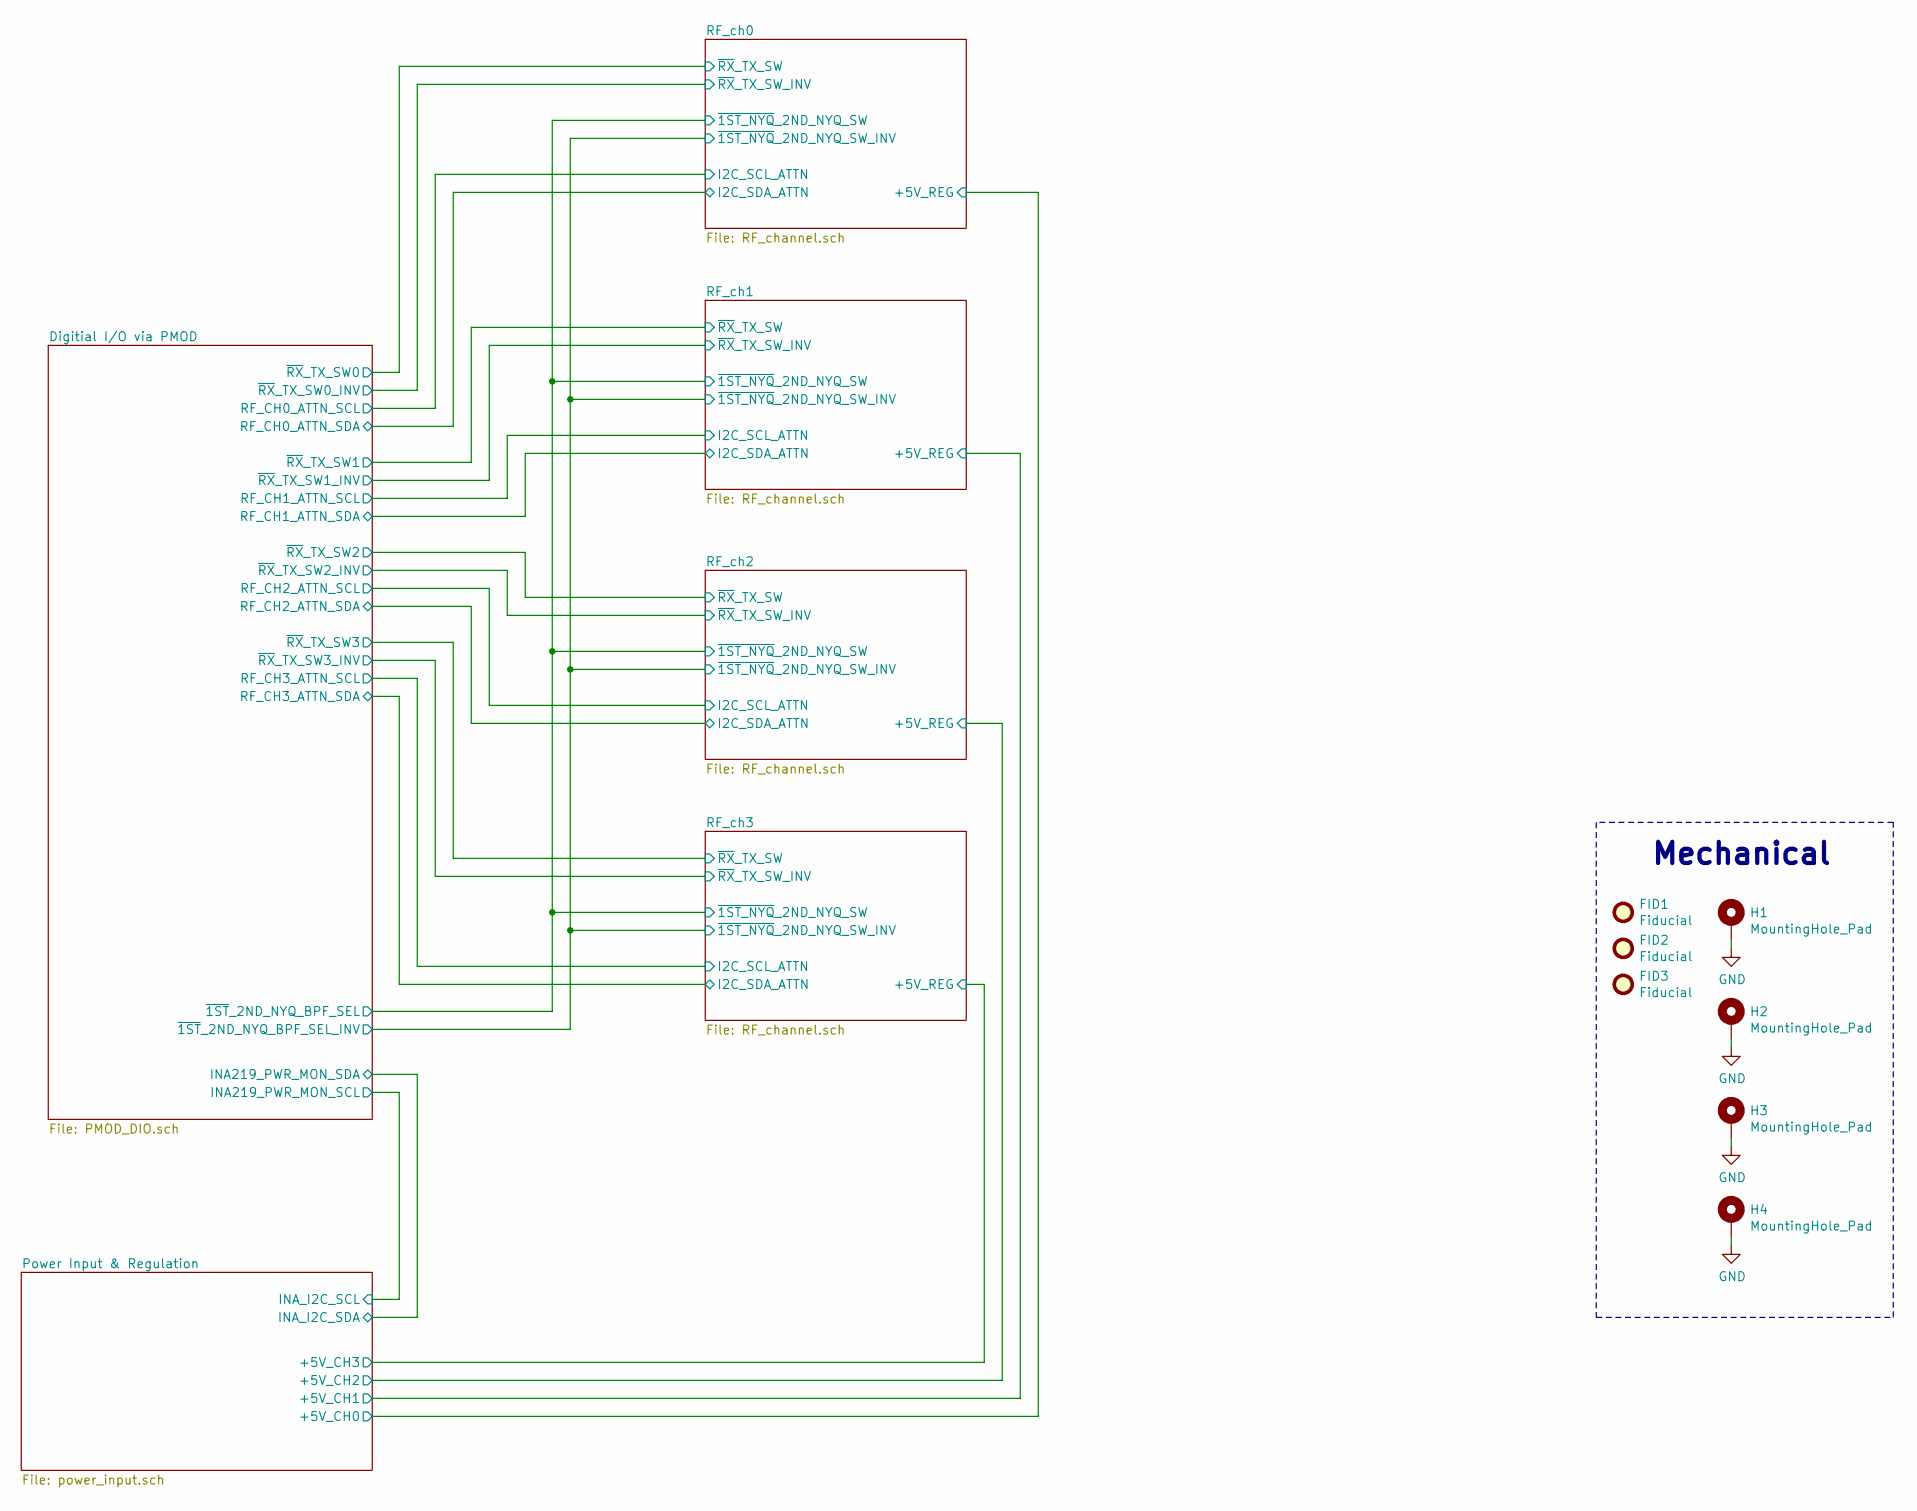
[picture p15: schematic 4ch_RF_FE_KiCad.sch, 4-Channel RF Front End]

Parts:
FID1, FID2, FID3: Fiducial; Fiducial_1mm_Mask2mm
H1, H2, H3, H4: MountingHole_Pad; MountingHole_3.7mm_Pad_Via

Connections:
GND: H1.1, H2.1, H3.1, H4.1; also elsewhere on the board

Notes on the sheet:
Mechanical

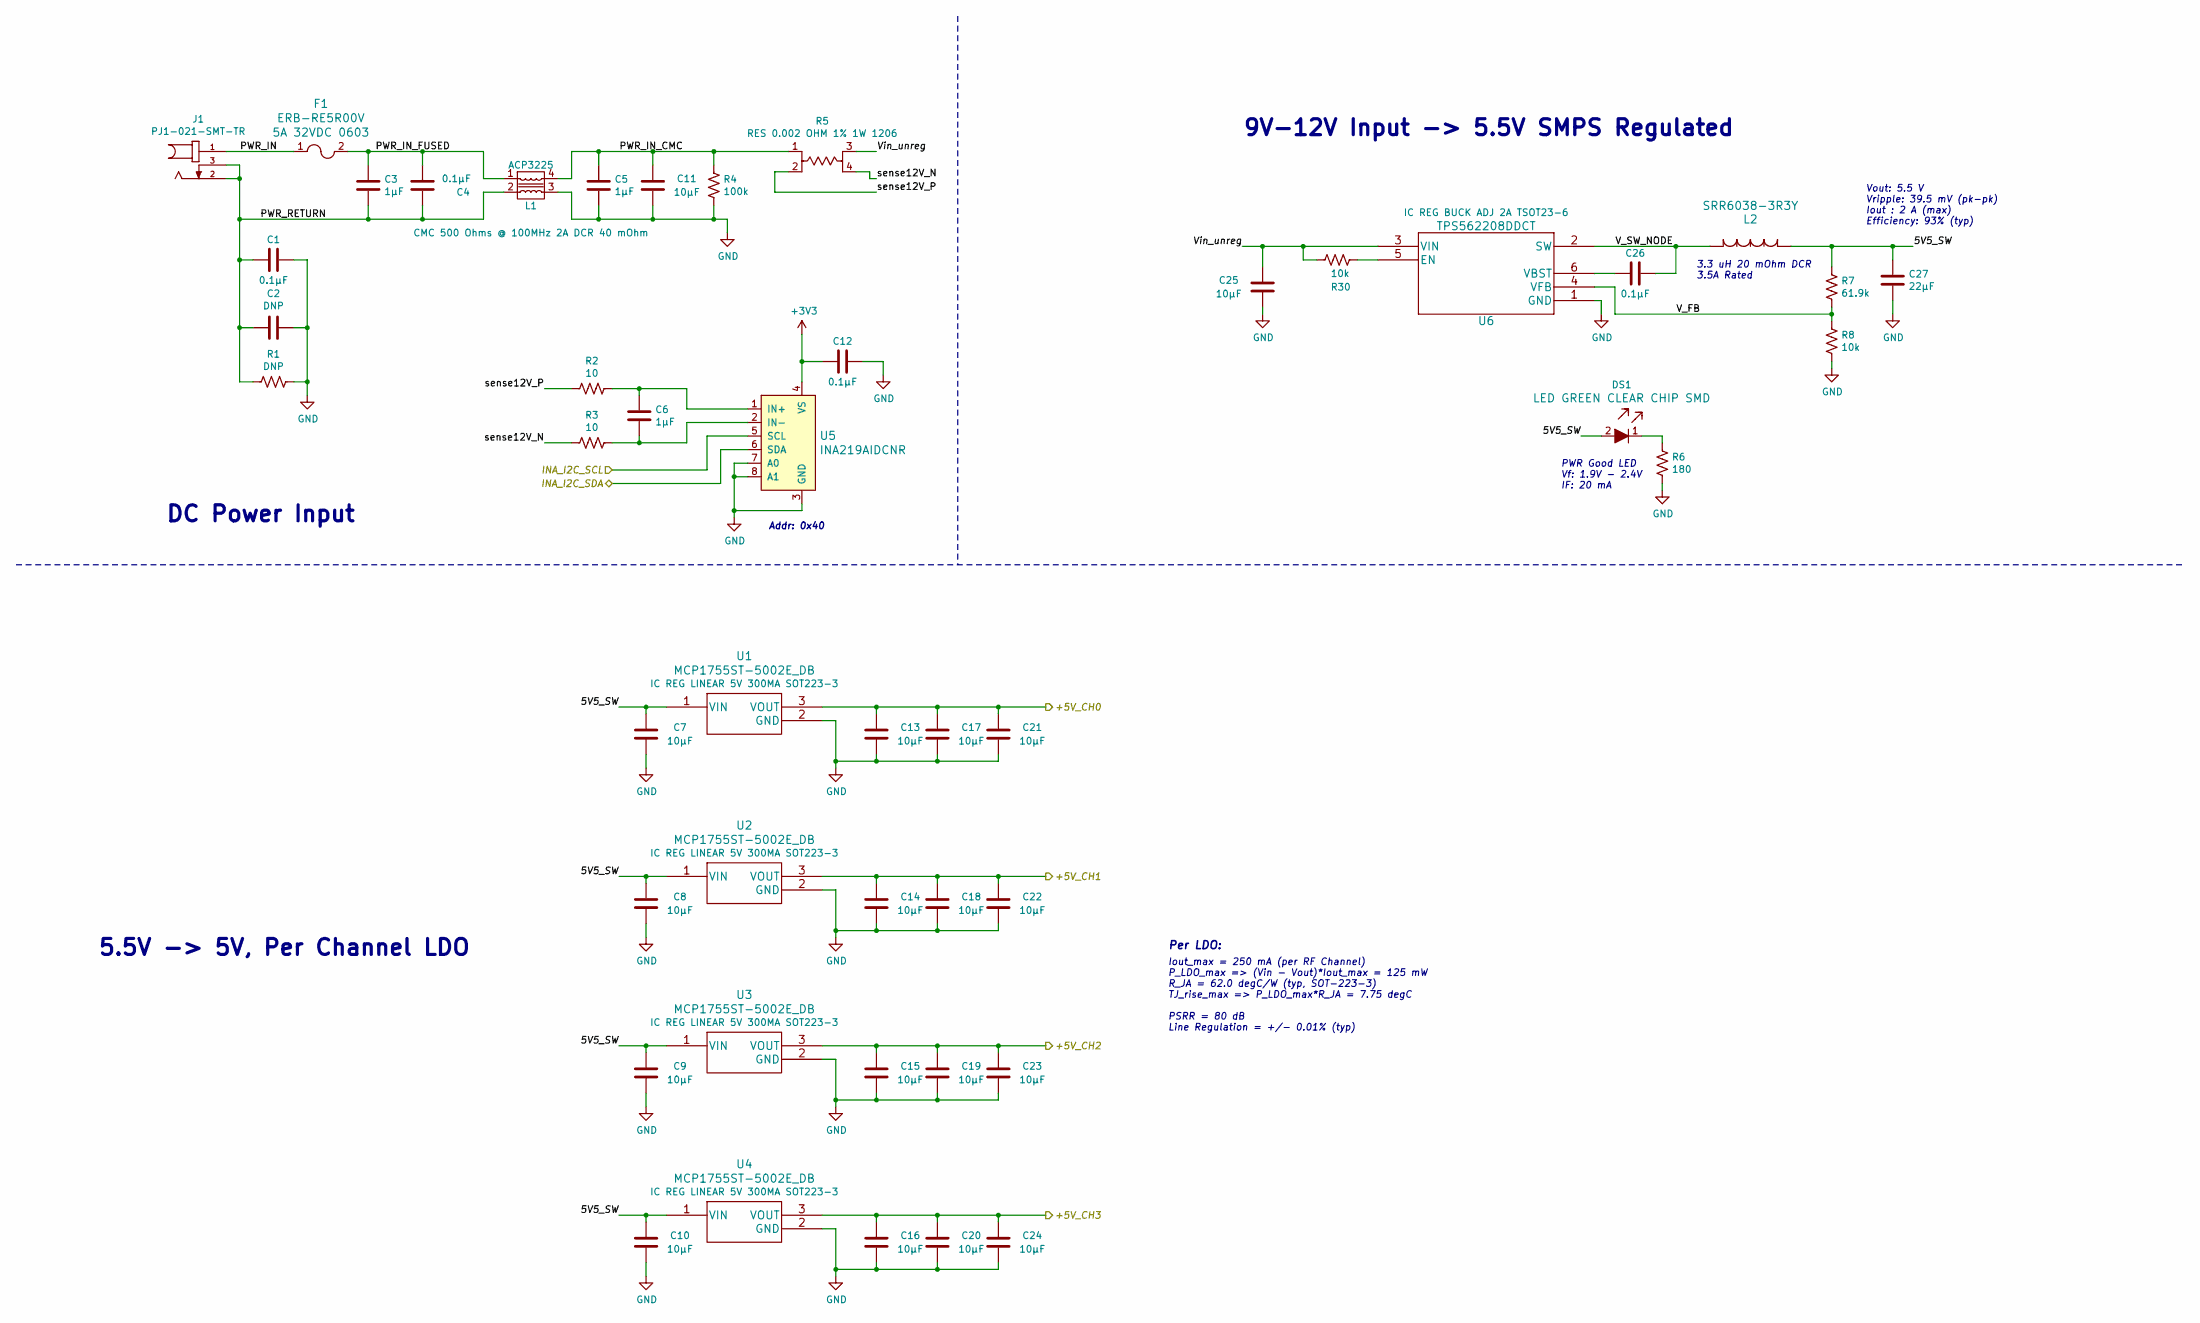
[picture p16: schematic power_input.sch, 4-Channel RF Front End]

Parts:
C1, C4, C12, C26: 0.1µF; C_0402_1005Metric; Digi-Key PN 490-13342-1-ND
C2: DNP; C_0402_1005Metric
C3, C5, C6: 1µF; C_0603_1608Metric_Pad1.05x0.95mm_HandSolder; Digi-Key PN 1276-1942-1-ND
C7, C8, C9, C10, C11, C13, C14, C15, C16, C17, C18, C19, C20, C21, C22, C23, C24, C25: 10µF; C_1206_3216Metric_Pad1.42x1.75mm_HandSolder; Digi-Key PN 1276-1804-1-ND
C27: 22µF; C_1206_3216Metric_Pad1.42x1.75mm_HandSolder; Digi-Key PN 1276-3146-1-ND
DS1: LTST-C190KGKT; LED_0603; MPN LTST-C190KGKT; Digi-Key_PN 160-1435-1-ND
F1: ERB-RE5R00V; 0603; Digi-Key_PN P15125CT-ND
J1: PJ1-021-SMT-TR; CUI_PJ1-021-SMT-TR; Digi-Key PN CP1-021PJCT-ND
L1: ACP3225; CMC_3225_2x2_LGA; Digi-Key PN 445-172408-1-ND
L2: SRR6038-3R3Y; Digi-Key PN SRR6038-3R3YCT-ND
R1: DNP; R_0402_1005Metric
R2, R3: 10; R_0402_1005Metric; Digi-Key PN 311-10.0LRCT-ND
R4: 100k; R_0402_1005Metric; Digi-Key PN 311-100KLRCT-ND
R5: CSR1206-0R002F1; CSR_4pin_1206_3216Metric_Pad1.42x1.75mm_HandSolder; Digi-Key PN 696-1370-1-ND
R6: 180; R_0603_1608Metric_Pad1.05x0.95mm_HandSolder; Digi-Key PN 311-180GRCT-ND
R7: 61.9k; R_0402_1005Metric; Digi-Key PN 311-61.9KLRCT-ND
R8, R30: 10k; R_0402_1005Metric; Digi-Key PN 311-10.0KLRCT-ND
U1, U2, U3, U4: MCP1755ST-5002E_DB; Digi-Key PN MCP1755ST-5002E/DBCT-ND
U5: INA219AIDCNR; SOT-23-8; MPN INA219AIDCNR; Digi-Key_PN 296-23770-1-ND
U6: TPS562208DDCT; Digi-Key PN 296-43806-1-ND

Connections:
+3V3: C12.1, U5.4 (VS); also elsewhere on the board
/Digitial I/O via PMOD/INA219_PWR_MON_SCL: U5.5 (SCL); also elsewhere on the board
/Digitial I/O via PMOD/INA219_PWR_MON_SDA: U5.6 (SDA); also elsewhere on the board
/Power Input & Regulation/5V5_SW: C7.1, C8.1, C9.1, C10.1, C27.1, DS1.2, L2.1, R7.1, U1.1 (VIN), U2.1 (VIN), U3.1 (VIN), U4.1 (VIN)
/Power Input & Regulation/+5V_CH0: C13.1, C17.1, C21.1, U1.3 (VOUT); also elsewhere on the board
/Power Input & Regulation/+5V_CH1: C14.1, C18.1, C22.1, U2.3 (VOUT); also elsewhere on the board
/Power Input & Regulation/+5V_CH2: C15.1, C19.1, C23.1, U3.3 (VOUT); also elsewhere on the board
/Power Input & Regulation/+5V_CH3: C16.1, C20.1, C24.1, U4.3 (VOUT); also elsewhere on the board
/Power Input & Regulation/PWR_IN: F1.1, J1.1
/Power Input & Regulation/PWR_IN_CMC: C5.1, C11.1, L1.4, R4.1, R5.1
/Power Input & Regulation/PWR_IN_FUSED: C3.1, C4.2, F1.2, L1.1
/Power Input & Regulation/PWR_RETURN: C1.1, C2.2, C3.2, C4.1, J1.2, J1.3, L1.2, R1.2
/Power Input & Regulation/V_FB: R7.2, R8.1, U6.4 (VFB)
/Power Input & Regulation/V_SW_NODE: C26.2, L2.2, U6.2 (SW)
/Power Input & Regulation/Vin_unreg: C25.1, R5.3, R30.2, U6.3 (VIN)
/Power Input & Regulation/sense12V_N: R3.2, R5.4
/Power Input & Regulation/sense12V_P: R2.2, R5.2
GND: C1.2, C2.1, C5.2, C7.2, C8.2, C9.2, C10.2, C11.2, C12.2, C13.2, C14.2, C15.2, C16.2, C17.2, C18.2, C19.2, C20.2, C21.2, C22.2, C23.2, C24.2, C25.2, C27.2, L1.3, R1.1, R4.2, R6.2, R8.2, U1.2 (GND), U2.2 (GND), U3.2 (GND), U4.2 (GND), U5.3 (GND), U5.7 (A0), U5.8 (A1), U6.1 (GND); also elsewhere on the board
unnamed: C6.1, R2.1, U5.1 (IN+)
unnamed: C6.2, R3.1, U5.2 (IN-)
unnamed: C26.1, U6.6 (VBST)
unnamed: DS1.1, R6.1
unnamed: R30.1, U6.5 (EN)

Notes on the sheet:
Addr: 0x40
3.3 uH 20 mOhm DCR 3.5A Rated
9V-12V Input -> 5.5V SMPS Regulated
Vout: 5.5 V Vripple: 39.5 mV (pk-pk) Iout : 2 A (max) Efficiency: 93% (typ)
PWR Good LED Vf: 1.9V - 2.4V IF: 20 mA
Iout_max = 250 mA (per RF Channel) P_LDO_max => (Vin - Vout)*Iout_max = 125 mW R_JA = 62.0 degC/W (typ, SOT-223-3) TJ_rise_max => P_LDO_max*R_JA = 7.75 degC PSRR = 80 dB Line Regulation = +/- 0.01% (typ)
DC Power Input
5.5V -> 5V, Per Channel LDO
Per LDO:

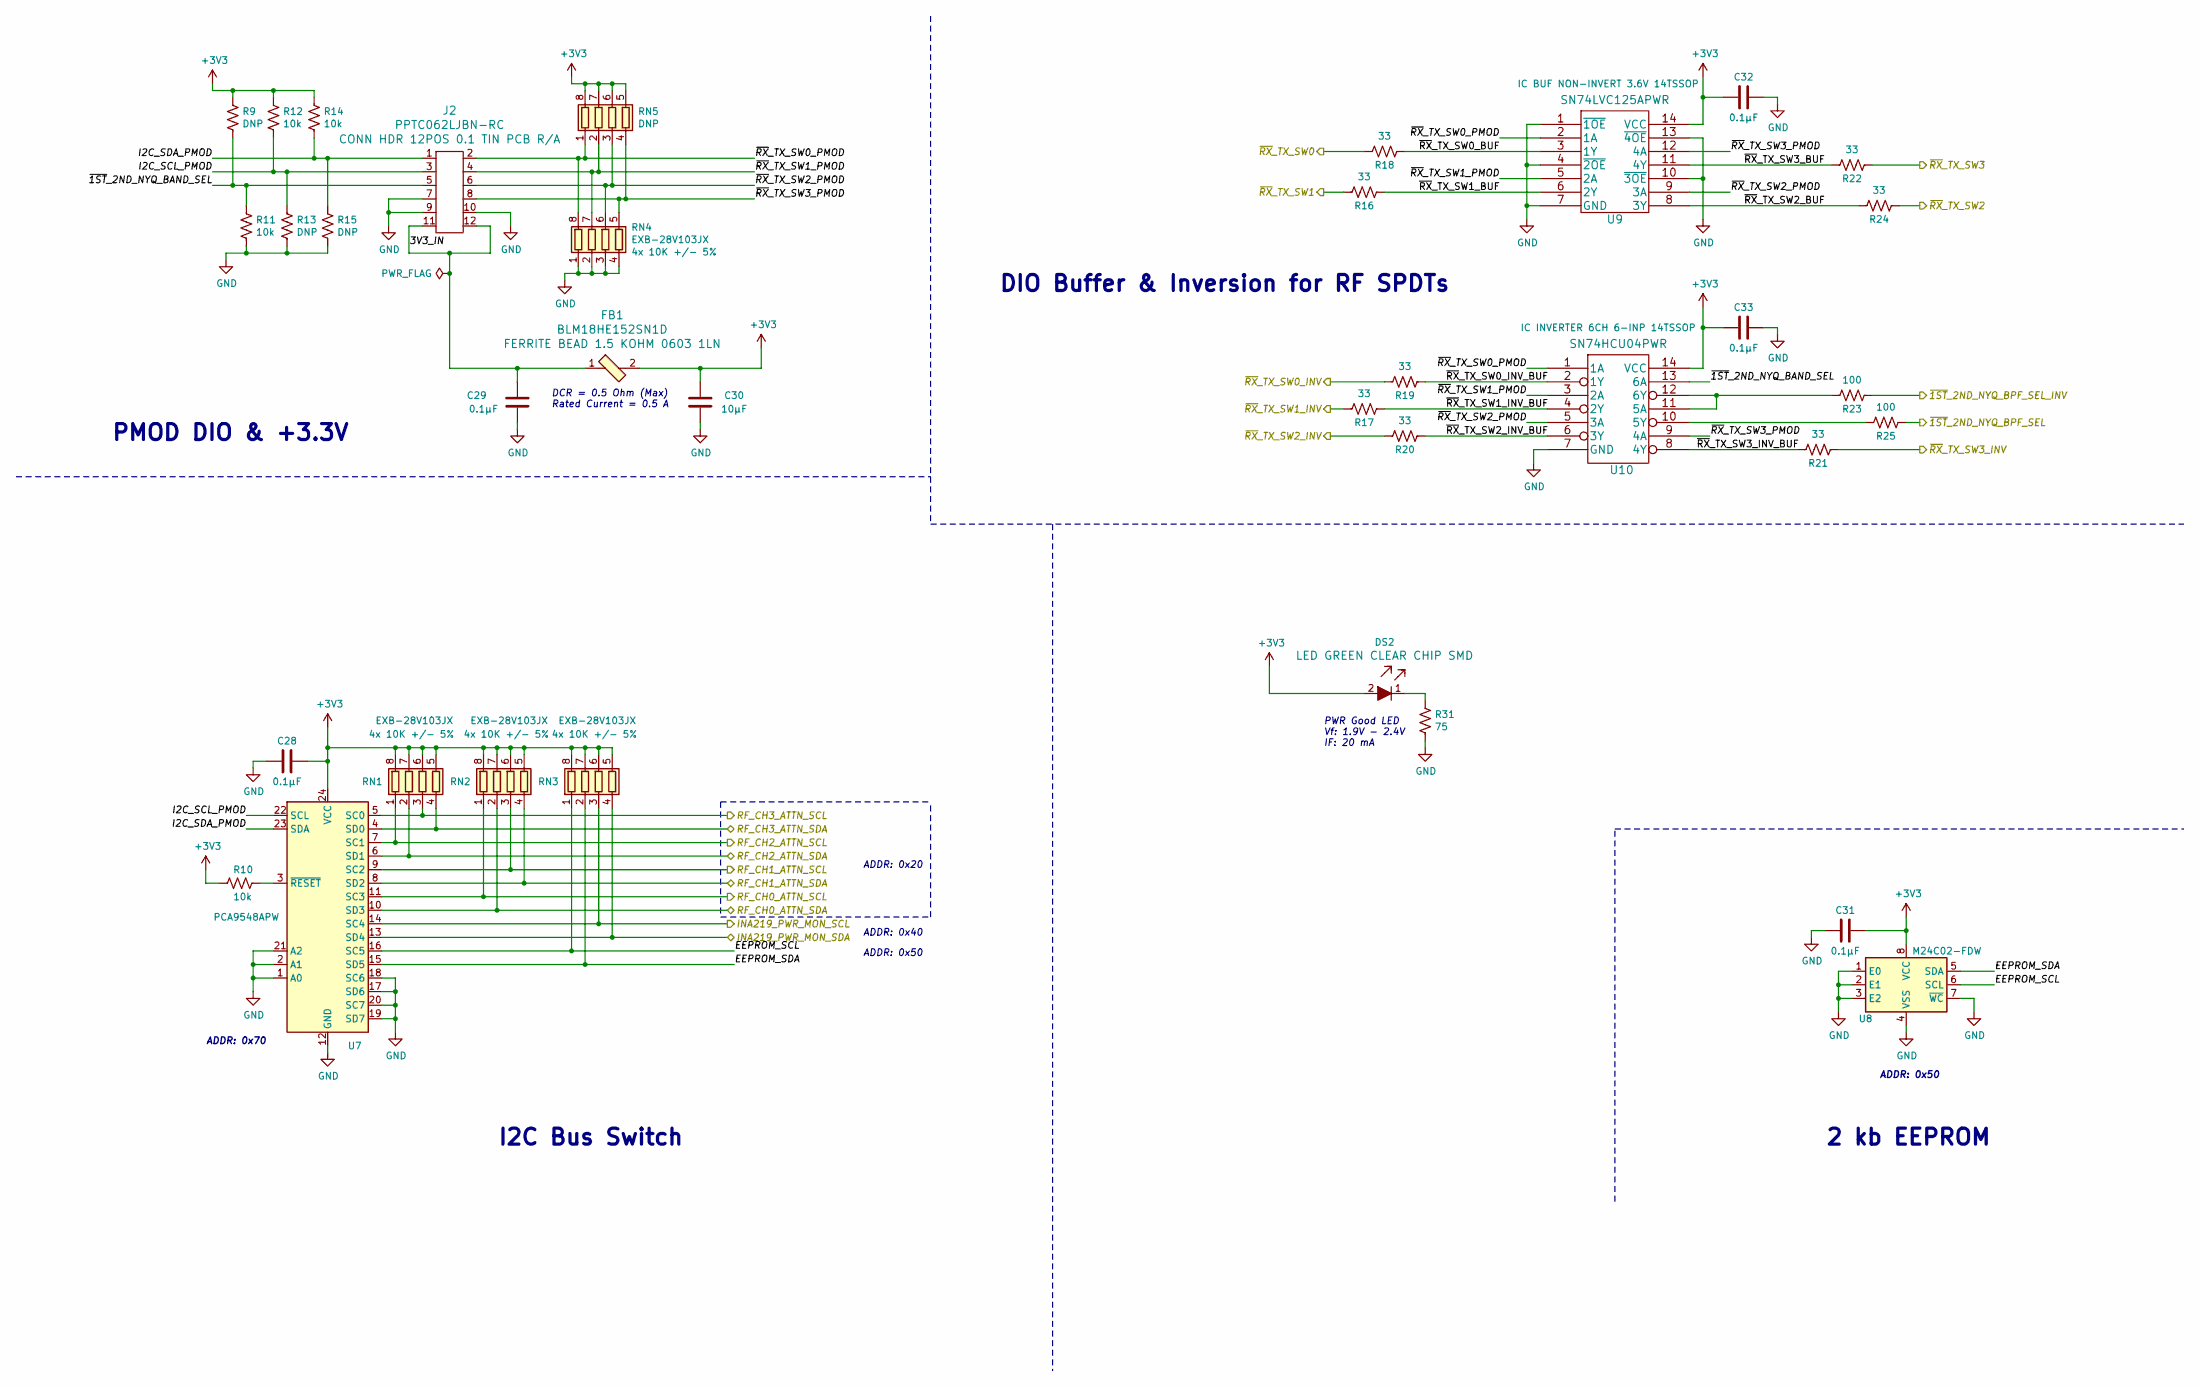
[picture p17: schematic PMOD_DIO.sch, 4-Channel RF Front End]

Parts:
C28, C29, C31, C32, C33: 0.1µF; C_0402_1005Metric; Digi-Key PN 490-13342-1-ND
C30: 10µF; C_1206_3216Metric_Pad1.42x1.75mm_HandSolder; Digi-Key PN 1276-1804-1-ND
DS2: LTST-C190KGKT; LED_0603; MPN LTST-C190KGKT; Digi-Key_PN 160-1435-1-ND
FB1: BLM18HE152SN1D; 0603; MPN BLM18HE152SN1D; Digi-Key_PN 490-5216-1-ND
J2: PPTC062LJBN-RC; PinHeader_2x06_P2.54mm_Horizontal; Digi-Key_PN S5520-ND
R9, R13, R15: DNP; R_0402_1005Metric
R10, R11, R12, R14: 10k; R_0402_1005Metric; Digi-Key PN 311-10.0KLRCT-ND
R16, R17, R18, R19, R20, R21, R22, R24: 33; R_0402_1005Metric; Digi-Key PN 311-33.0LRCT-ND
R23, R25: 100; R_0402_1005Metric; Digi-Key PN 311-100LRCT-ND
R31: 75; R_0603_1608Metric_Pad1.05x0.95mm_HandSolder; Digi-Key PN 311-75.0HRCT-ND
RN1, RN2, RN3, RN4: EXB-28V103JX; R_Array_Convex_4x0402; Digi-Key PN Y7103CT-ND
RN5: DNP; R_Array_Convex_4x0402
U7: PCA9548APW; TSSOP-24_4.4x7.8mm_P0.65mm
U8: M24C02-FDW; TSSOP-8_4.4x3mm_P0.65mm
U9: SN74LVC125APWR; Digi-Key PN 296-1222-1-ND
U10: SN74HCU04PWR; Digi-Key PN 296-9821-1-ND

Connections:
+3V3: C28.1, C30.1, C31.1, C32.2, C33.2, DS2.2, FB1.2, R9.1, R10.2, R12.1, R14.1, RN1.5 (R4.2), RN1.6 (R3.2), RN1.7 (R2.2), RN1.8 (R1.2), RN2.5 (R4.2), RN2.6 (R3.2), RN2.7 (R2.2), RN2.8 (R1.2), RN3.5 (R4.2), RN3.6 (R3.2), RN3.7 (R2.2), RN3.8 (R1.2), RN5.5 (R4.2), RN5.6 (R3.2), RN5.7 (R2.2), RN5.8 (R1.2), U7.24 (VCC), U8.8 (VCC), U9.14 (VCC), U10.14 (VCC); also elsewhere on the board
/Digitial I/O via PMOD/3V3_IN: C29.1, FB1.1, J2.11, J2.12
/Digitial I/O via PMOD/EEPROM_SCL: RN3.1 (R1.1), U7.16 (SC5), U8.6 (SCL)
/Digitial I/O via PMOD/EEPROM_SDA: RN3.2 (R2.1), U7.15 (SD5), U8.5 (SDA)
/Digitial I/O via PMOD/I2C_SCL_PMOD: J2.3, R12.2, R13.1, U7.22 (SCL)
/Digitial I/O via PMOD/I2C_SDA_PMOD: J2.1, R14.2, R15.1, U7.23 (SDA)
/Digitial I/O via PMOD/INA219_PWR_MON_SCL: RN3.3 (R3.1), U7.14 (SC4); also elsewhere on the board
/Digitial I/O via PMOD/INA219_PWR_MON_SDA: RN3.4 (R4.1), U7.13 (SD4); also elsewhere on the board
/Digitial I/O via PMOD/~1ST~_2ND_NYQ_BAND_SEL: J2.5, R9.2, R11.1, U10.13 (6A)
/Digitial I/O via PMOD/~RX~_TX_SW0_BUF: R18.1, U9.3 (1Y)
/Digitial I/O via PMOD/~RX~_TX_SW0_INV: R19.2; also elsewhere on the board
/Digitial I/O via PMOD/~RX~_TX_SW0_INV_BUF: R19.1, U10.2 (1Y)
/Digitial I/O via PMOD/~RX~_TX_SW0_PMOD: J2.2, RN4.8 (R1.2), RN5.1 (R1.1), U9.2 (1A), U10.1 (1A)
/Digitial I/O via PMOD/~RX~_TX_SW1_BUF: R16.1, U9.6 (2Y)
/Digitial I/O via PMOD/~RX~_TX_SW1_INV: R17.2; also elsewhere on the board
/Digitial I/O via PMOD/~RX~_TX_SW1_INV_BUF: R17.1, U10.4 (2Y)
/Digitial I/O via PMOD/~RX~_TX_SW1_PMOD: J2.4, RN4.7 (R2.2), RN5.2 (R2.1), U9.5 (2A), U10.3 (2A)
/Digitial I/O via PMOD/~RX~_TX_SW2_BUF: R24.2, U9.8 (3Y)
/Digitial I/O via PMOD/~RX~_TX_SW2_INV: R20.2; also elsewhere on the board
/Digitial I/O via PMOD/~RX~_TX_SW2_INV_BUF: R20.1, U10.6 (3Y)
/Digitial I/O via PMOD/~RX~_TX_SW2_PMOD: J2.6, RN4.6 (R3.2), RN5.3 (R3.1), U9.9 (3A), U10.5 (3A)
/Digitial I/O via PMOD/~RX~_TX_SW3_BUF: R22.2, U9.11 (4Y)
/Digitial I/O via PMOD/~RX~_TX_SW3_INV: R21.1; also elsewhere on the board
/Digitial I/O via PMOD/~RX~_TX_SW3_INV_BUF: R21.2, U10.8 (4Y)
/Digitial I/O via PMOD/~RX~_TX_SW3_PMOD: J2.8, RN4.5 (R4.2), RN5.4 (R4.1), U9.12 (4A), U10.9 (4A)
/RF_ch0/I2C_SCL_ATTN: RN2.1 (R1.1), U7.11 (SC3); also elsewhere on the board
/RF_ch0/I2C_SDA_ATTN: RN2.2 (R2.1), U7.10 (SD3); also elsewhere on the board
/RF_ch0/~1ST_NYQ~_2ND_NYQ_SW: R25.1; also elsewhere on the board
/RF_ch0/~1ST_NYQ~_2ND_NYQ_SW_INV: R23.1; also elsewhere on the board
/RF_ch0/~RX~_TX_SW: R18.2; also elsewhere on the board
/RF_ch1/I2C_SCL_ATTN: RN2.3 (R3.1), U7.9 (SC2); also elsewhere on the board
/RF_ch1/I2C_SDA_ATTN: RN2.4 (R4.1), U7.8 (SD2); also elsewhere on the board
/RF_ch1/~RX~_TX_SW: R16.2; also elsewhere on the board
/RF_ch2/I2C_SCL_ATTN: RN1.1 (R1.1), U7.7 (SC1); also elsewhere on the board
/RF_ch2/I2C_SDA_ATTN: RN1.2 (R2.1), U7.6 (SD1); also elsewhere on the board
/RF_ch2/~RX~_TX_SW: R24.1; also elsewhere on the board
/RF_ch3/I2C_SCL_ATTN: RN1.3 (R3.1), U7.5 (SC0); also elsewhere on the board
/RF_ch3/I2C_SDA_ATTN: RN1.4 (R4.1), U7.4 (SD0); also elsewhere on the board
/RF_ch3/~RX~_TX_SW: R22.1; also elsewhere on the board
GND: C28.2, C29.2, C30.2, C31.2, C32.1, C33.1, J2.7, J2.9, J2.10, R11.2, R13.2, R15.2, R31.2, RN4.1 (R1.1), RN4.2 (R2.1), RN4.3 (R3.1), RN4.4 (R4.1), U7.1 (A0), U7.2 (A1), U7.12 (GND), U7.17 (SD6), U7.18 (SC6), U7.19 (SD7), U7.20 (SC7), U7.21 (A2), U8.1 (E0), U8.2 (E1), U8.3 (E2), U8.4 (VSS), U8.7 (~WC), U9.1 (~1OE), U9.4 (~2OE), U9.7 (GND), U9.10 (~3OE), U9.13 (~4OE), U10.7 (GND); also elsewhere on the board
unnamed: DS2.1, R31.1
unnamed: R10.1, U7.3 (~RESET)
unnamed: R23.2, U10.11 (5A), U10.12 (6Y)
unnamed: R25.2, U10.10 (5Y)

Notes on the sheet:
DCR = 0.5 Ohm (Max) Rated Current = 0.5 A
PMOD DIO & +3.3V
ADDR: 0x20
ADDR: 0x40
ADDR: 0x50
2 kb EEPROM
ADDR: 0x70
DIO Buffer & Inversion for RF SPDTs
I2C Bus Switch
PWR Good LED Vf: 1.9V - 2.4V IF: 20 mA

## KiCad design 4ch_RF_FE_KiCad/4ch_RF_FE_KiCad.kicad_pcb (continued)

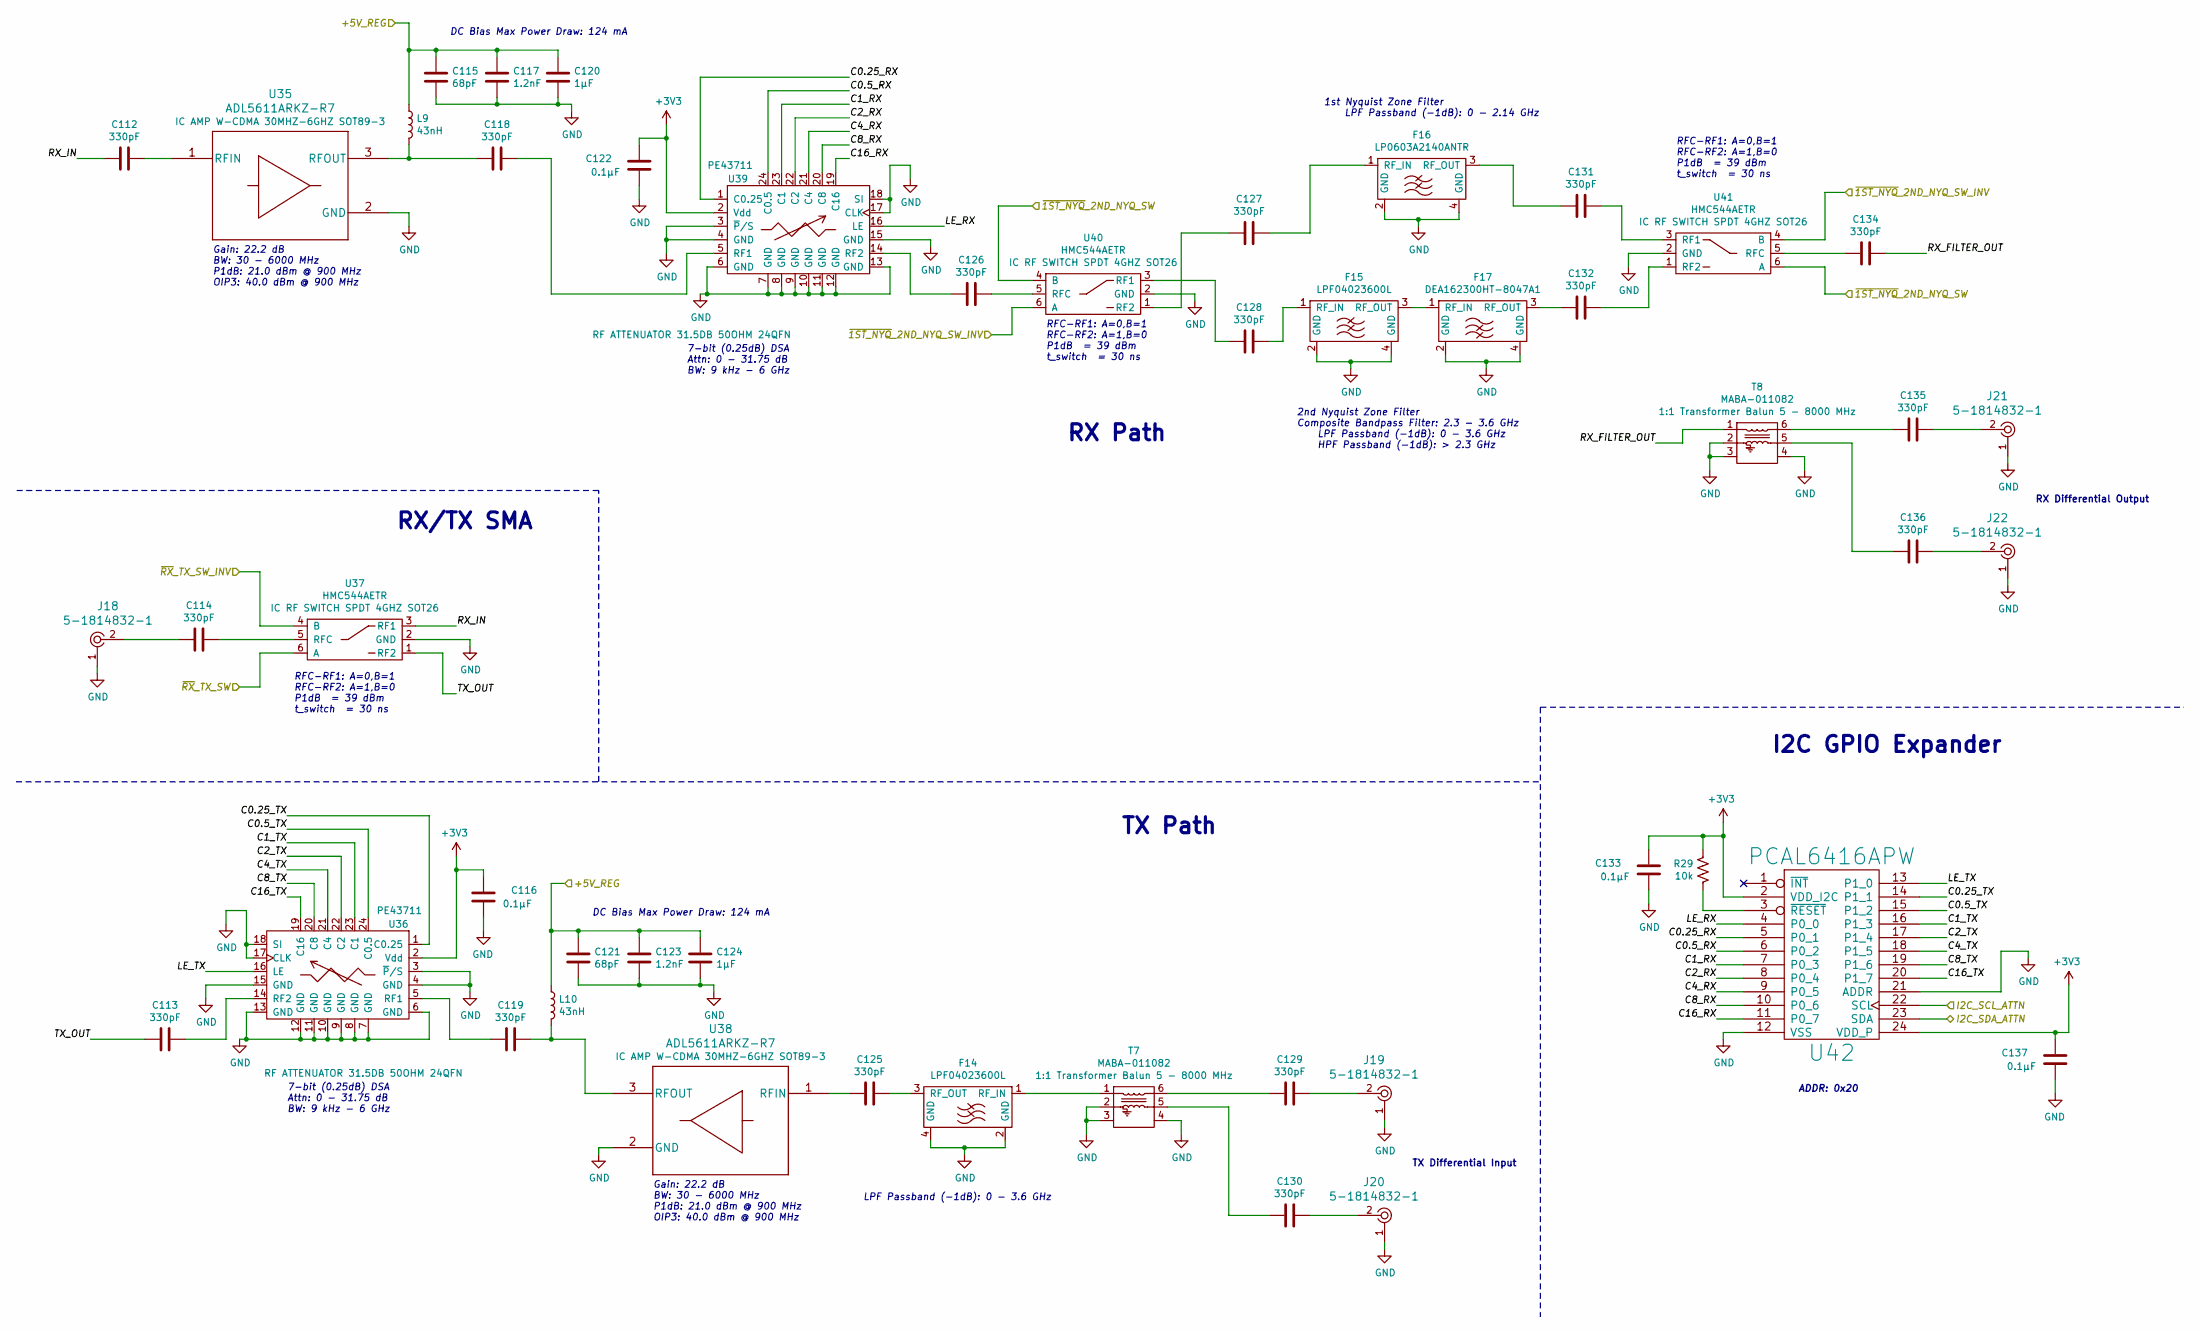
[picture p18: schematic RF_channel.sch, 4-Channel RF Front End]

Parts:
C34, C35, C36, C40, C41, C47, C48, C49, C50, C51, C52, C53, C54, C56, C57, C58: 330pF; C_0402_1005Metric; Digi-Key PN 399-7787-1-ND
C37, C43: 68pF; C_0402_1005Metric; Digi-Key PN 399-19382-1-ND
C38, C44, C55, C59: 0.1µF; C_0402_1005Metric; Digi-Key PN 490-13342-1-ND
C39, C45: 1.2nF; C_0603_1608Metric_Pad1.05x0.95mm_HandSolder; Digi-Key PN 399-7851-1-ND
C42, C46: 1µF; C_0603_1608Metric_Pad1.05x0.95mm_HandSolder; Digi-Key PN 1276-1942-1-ND
F2, F3: LPF04023600L; F_0402_1005Metric_2x2_LGA; Digi-Key PN 1284-1984-1-ND
F4: LP0603A2140ANTR; F_0603_2x2_LGA; Digi-Key PN 478-2914-1-ND
F5: DEA162300HT-8047A1; F_DEA16_LGA; Digi-Key PN 445-175383-1-ND
J3, J4, J5, J6, J7: 5-1814832-1; RF_SMA_Vertical_5-1814832-1; MPN 5-1814832-1; Digi-Key_PN A97594-ND
L3, L4: 43nH; L_0603_1608Metric_Pad1.05x0.95mm_HandSolder; Digi-Key PN 490-6892-1-ND
R29: 10k; R_0402_1005Metric; Digi-Key PN 311-10.0KLRCT-ND
T1, T2: MABA-011082; T_6pin_23_balun; Digi-Key PN 1465-1843-1-ND
U11, U14: ADL5611ARKZ-R7; Digi-Key PN ADL5611ARKZ-R7CT-ND
U12, U15: PE43711; QFN-24-1EP_4x4mm_P0.5mm_EP2.7x2.7mm; Digi-Key PN 1046-1138-1-ND
U13, U16, U17: HMC544AETR; SOT-23-6_Handsoldering; Digi-Key PN 1127-1856-1-ND
U18: PCAL6416APW; TSSOP-24_W4.40mm; Digi-Key PN 568-9922-1-ND

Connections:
+3V3: C38.1, C44.1, C55.1, C59.1, R29.1, U12.2 (Vdd), U15.2 (Vdd), U18.2 (VDD_I2C), U18.24 (VDD_P); also elsewhere on the board
/Digitial I/O via PMOD/~RX~_TX_SW0_INV: U13.4 (B); also elsewhere on the board
/Power Input & Regulation/+5V_CH0: C37.1, C39.1, C42.1, C43.1, C45.1, C46.1, L3.1, L4.1; also elsewhere on the board
/RF_ch0/C0.5_RX: U15.24 (C0.5), U18.6 (P0_2)
/RF_ch0/C0.5_TX: U12.24 (C0.5), U18.15 (P1_2)
/RF_ch0/C0.25_RX: U15.1 (C0.25), U18.5 (P0_1)
/RF_ch0/C0.25_TX: U12.1 (C0.25), U18.14 (P1_1)
/RF_ch0/C1_RX: U15.23 (C1), U18.7 (P0_3)
/RF_ch0/C1_TX: U12.23 (C1), U18.16 (P1_3)
/RF_ch0/C2_RX: U15.22 (C2), U18.8 (P0_4)
/RF_ch0/C2_TX: U12.22 (C2), U18.17 (P1_4)
/RF_ch0/C4_RX: U15.21 (C4), U18.9 (P0_5)
/RF_ch0/C4_TX: U12.21 (C4), U18.18 (P1_5)
/RF_ch0/C8_RX: U15.20 (C8), U18.10 (P0_6)
/RF_ch0/C8_TX: U12.20 (C8), U18.19 (P1_6)
/RF_ch0/C16_RX: U15.19 (C16), U18.11 (P0_7)
/RF_ch0/C16_TX: U12.19 (C16), U18.20 (P1_7)
/RF_ch0/I2C_SCL_ATTN: U18.22 (SCL); also elsewhere on the board
/RF_ch0/I2C_SDA_ATTN: U18.23 (SDA); also elsewhere on the board
/RF_ch0/LE_RX: U15.16 (LE), U18.4 (P0_0)
/RF_ch0/LE_TX: U12.16 (LE), U18.13 (P1_0)
/RF_ch0/RX_FILTER_OUT: C56.1, T2.1
/RF_ch0/RX_IN: C34.2, U13.3 (RF1)
/RF_ch0/TX_OUT: C35.2, U13.1 (RF2)
/RF_ch0/~1ST_NYQ~_2ND_NYQ_SW: U16.4 (B), U17.6 (A); also elsewhere on the board
/RF_ch0/~1ST_NYQ~_2ND_NYQ_SW_INV: U16.6 (A), U17.4 (B); also elsewhere on the board
/RF_ch0/~RX~_TX_SW: U13.6 (A); also elsewhere on the board
GND: C37.2, C38.2, C39.2, C42.2, C43.2, C44.2, C45.2, C46.2, C55.2, C59.2, F2.2 (GND), F2.4 (GND), F3.2 (GND), F3.4 (GND), F4.2 (GND), F4.4 (GND), F5.2 (GND), F5.4 (GND), J3.1, J4.1, J5.1, J6.1, J7.1, T1.2, T1.3, T1.4, T2.2, T2.3, T2.4, U11.2 (GND), U12.3 (~P~/S), U12.4 (GND), U12.6 (GND), U12.7 (GND), U12.8 (GND), U12.9 (GND), U12.10 (GND), U12.11 (GND), U12.12 (GND), U12.13 (GND), U12.15 (GND), U12.17 (CLK), U12.18 (SI), U13.2 (GND), U14.2 (GND), U15.3 (~P~/S), U15.4 (GND), U15.6 (GND), U15.7 (GND), U15.8 (GND), U15.9 (GND), U15.10 (GND), U15.11 (GND), U15.12 (GND), U15.13 (GND), U15.15 (GND), U15.17 (CLK), U15.18 (SI), U16.2 (GND), U17.2 (GND), U18.12 (VSS), U18.21 (ADDR); also elsewhere on the board
unnamed: C34.1, U11.1 (RFIN)
unnamed: C35.1, U12.14 (RF2)
unnamed: C36.1, U13.5 (RFC)
unnamed: C36.2, J3.2
unnamed: C40.1, U15.5 (RF1)
unnamed: C40.2, L3.2, U11.3 (RFOUT)
unnamed: C41.1, L4.2, U14.3 (RFOUT)
unnamed: C41.2, U12.5 (RF1)
unnamed: C47.1, F2.3 (RF_OUT)
unnamed: C47.2, U14.1 (RFIN)
unnamed: C48.1, U16.5 (RFC)
unnamed: C48.2, U15.14 (RF2)
unnamed: C49.1, F4.1 (RF_IN)
unnamed: C49.2, U16.1 (RF2)
unnamed: C50.1, F3.1 (RF_IN)
unnamed: C50.2, U16.3 (RF1)
unnamed: C51.1, J4.2
unnamed: C51.2, T1.6
unnamed: C52.1, J5.2
unnamed: C52.2, T1.5
unnamed: C53.1, U17.3 (RF1)
unnamed: C53.2, F4.3 (RF_OUT)
unnamed: C54.1, U17.1 (RF2)
unnamed: C54.2, F5.3 (RF_OUT)
unnamed: C56.2, U17.5 (RFC)
unnamed: C57.1, J6.2
unnamed: C57.2, T2.6
unnamed: C58.1, J7.2
unnamed: C58.2, T2.5
unnamed: F2.1 (RF_IN), T1.1
unnamed: F3.3 (RF_OUT), F5.1 (RF_IN)

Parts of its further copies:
C60, C61, C62, C66, C67, C73, C74, C75, C76, C77, C78, C79, C80, C82, C83, C84, C86, C87, C88, C92, C93, C99, C100, C101, C102, C103, C104, C105, C106, C108, C109, C110, C112, C113, C114, C118, C119, C125, C126, C127, C128, C129, C130, C131, C132, C134, C135, C136: 330pF; C_0402_1005Metric; Digi-Key PN 399-7787-1-ND
C63, C69, C89, C95, C115, C121: 68pF; C_0402_1005Metric; Digi-Key PN 399-19382-1-ND
C64, C70, C81, C85, C90, C96, C107, C111, C116, C122, C133, C137: 0.1µF; C_0402_1005Metric; Digi-Key PN 490-13342-1-ND
C65, C71, C91, C97, C117, C123: 1.2nF; C_0603_1608Metric_Pad1.05x0.95mm_HandSolder; Digi-Key PN 399-7851-1-ND
C68, C72, C94, C98, C120, C124: 1µF; C_0603_1608Metric_Pad1.05x0.95mm_HandSolder; Digi-Key PN 1276-1942-1-ND
F6, F7, F10, F11, F14, F15: LPF04023600L; F_0402_1005Metric_2x2_LGA; Digi-Key PN 1284-1984-1-ND
F8, F12, F16: LP0603A2140ANTR; F_0603_2x2_LGA; Digi-Key PN 478-2914-1-ND
F9, F13, F17: DEA162300HT-8047A1; F_DEA16_LGA; Digi-Key PN 445-175383-1-ND
J8, J9, J10, J11, J12, J13, J14, J15, J16, J17, J18, J19, J20, J21, J22: 5-1814832-1; RF_SMA_Vertical_5-1814832-1; MPN 5-1814832-1; Digi-Key_PN A97594-ND
L5, L6, L7, L8, L9, L10: 43nH; L_0603_1608Metric_Pad1.05x0.95mm_HandSolder; Digi-Key PN 490-6892-1-ND
R26, R27, R28: 10k; R_0402_1005Metric; Digi-Key PN 311-10.0KLRCT-ND
T3, T4, T5, T6, T7, T8: MABA-011082; T_6pin_23_balun; Digi-Key PN 1465-1843-1-ND
U20, U23, U28, U31, U36, U39: PE43711; QFN-24-1EP_4x4mm_P0.5mm_EP2.7x2.7mm; Digi-Key PN 1046-1138-1-ND
U21, U24, U25, U29, U32, U33, U37, U40, U41: HMC544AETR; SOT-23-6_Handsoldering; Digi-Key PN 1127-1856-1-ND
U26, U34, U42: PCAL6416APW; TSSOP-24_W4.40mm; Digi-Key PN 568-9922-1-ND

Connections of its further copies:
+3V3: C64.1, C70.1, C81.1, C85.1, C90.1, C96.1, C107.1, C111.1, C116.1, C122.1, C133.1, C137.1, R26.1, R27.1, R28.1, U20.2 (Vdd), U23.2 (Vdd), U26.2 (VDD_I2C), U26.24 (VDD_P), U28.2 (Vdd), U31.2 (Vdd), U34.2 (VDD_I2C), U34.24 (VDD_P), U36.2 (Vdd), U39.2 (Vdd), U42.2 (VDD_I2C), U42.24 (VDD_P); also elsewhere on the board
/Digitial I/O via PMOD/~RX~_TX_SW1_INV: U21.4 (B); also elsewhere on the board
/Digitial I/O via PMOD/~RX~_TX_SW2_INV: U37.4 (B); also elsewhere on the board
/Digitial I/O via PMOD/~RX~_TX_SW3_INV: U29.4 (B); also elsewhere on the board
/Power Input & Regulation/+5V_CH1: C63.1, C65.1, C68.1, C69.1, C71.1, C72.1, L5.1, L6.1; also elsewhere on the board
/Power Input & Regulation/+5V_CH2: C115.1, C117.1, C120.1, C121.1, C123.1, C124.1, L9.1, L10.1; also elsewhere on the board
/Power Input & Regulation/+5V_CH3: C89.1, C91.1, C94.1, C95.1, C97.1, C98.1, L7.1, L8.1; also elsewhere on the board
/RF_ch0/~1ST_NYQ~_2ND_NYQ_SW: U24.4 (B), U25.6 (A), U32.4 (B), U33.6 (A), U40.4 (B), U41.6 (A); also elsewhere on the board
/RF_ch0/~1ST_NYQ~_2ND_NYQ_SW_INV: U24.6 (A), U25.4 (B), U32.6 (A), U33.4 (B), U40.6 (A), U41.4 (B); also elsewhere on the board
/RF_ch1/C0.5_RX: U23.24 (C0.5), U26.6 (P0_2)
/RF_ch1/C0.5_TX: U20.24 (C0.5), U26.15 (P1_2)
/RF_ch1/C0.25_RX: U23.1 (C0.25), U26.5 (P0_1)
/RF_ch1/C0.25_TX: U20.1 (C0.25), U26.14 (P1_1)
/RF_ch1/C1_RX: U23.23 (C1), U26.7 (P0_3)
/RF_ch1/C1_TX: U20.23 (C1), U26.16 (P1_3)
/RF_ch1/C2_RX: U23.22 (C2), U26.8 (P0_4)
/RF_ch1/C2_TX: U20.22 (C2), U26.17 (P1_4)
/RF_ch1/C4_RX: U23.21 (C4), U26.9 (P0_5)
/RF_ch1/C4_TX: U20.21 (C4), U26.18 (P1_5)
/RF_ch1/C8_RX: U23.20 (C8), U26.10 (P0_6)
/RF_ch1/C8_TX: U20.20 (C8), U26.19 (P1_6)
/RF_ch1/C16_RX: U23.19 (C16), U26.11 (P0_7)
/RF_ch1/C16_TX: U20.19 (C16), U26.20 (P1_7)
/RF_ch1/I2C_SCL_ATTN: U26.22 (SCL); also elsewhere on the board
/RF_ch1/I2C_SDA_ATTN: U26.23 (SDA); also elsewhere on the board
/RF_ch1/LE_RX: U23.16 (LE), U26.4 (P0_0)
/RF_ch1/LE_TX: U20.16 (LE), U26.13 (P1_0)
/RF_ch1/RX_FILTER_OUT: C82.1, T4.1
/RF_ch1/RX_IN: C60.2, U21.3 (RF1)
/RF_ch1/TX_OUT: C61.2, U21.1 (RF2)
/RF_ch1/~RX~_TX_SW: U21.6 (A); also elsewhere on the board
/RF_ch2/C0.5_RX: U39.24 (C0.5), U42.6 (P0_2)
/RF_ch2/C0.5_TX: U36.24 (C0.5), U42.15 (P1_2)
/RF_ch2/C0.25_RX: U39.1 (C0.25), U42.5 (P0_1)
/RF_ch2/C0.25_TX: U36.1 (C0.25), U42.14 (P1_1)
/RF_ch2/C1_RX: U39.23 (C1), U42.7 (P0_3)
/RF_ch2/C1_TX: U36.23 (C1), U42.16 (P1_3)
/RF_ch2/C2_RX: U39.22 (C2), U42.8 (P0_4)
/RF_ch2/C2_TX: U36.22 (C2), U42.17 (P1_4)
/RF_ch2/C4_RX: U39.21 (C4), U42.9 (P0_5)
/RF_ch2/C4_TX: U36.21 (C4), U42.18 (P1_5)
/RF_ch2/C8_RX: U39.20 (C8), U42.10 (P0_6)
/RF_ch2/C8_TX: U36.20 (C8), U42.19 (P1_6)
/RF_ch2/C16_RX: U39.19 (C16), U42.11 (P0_7)
/RF_ch2/C16_TX: U36.19 (C16), U42.20 (P1_7)
/RF_ch2/I2C_SCL_ATTN: U42.22 (SCL); also elsewhere on the board
/RF_ch2/I2C_SDA_ATTN: U42.23 (SDA); also elsewhere on the board
/RF_ch2/LE_RX: U39.16 (LE), U42.4 (P0_0)
/RF_ch2/LE_TX: U36.16 (LE), U42.13 (P1_0)
/RF_ch2/RX_FILTER_OUT: C134.1, T8.1
/RF_ch2/RX_IN: C112.2, U37.3 (RF1)
/RF_ch2/TX_OUT: C113.2, U37.1 (RF2)
/RF_ch2/~RX~_TX_SW: U37.6 (A); also elsewhere on the board
/RF_ch3/C0.5_RX: U31.24 (C0.5), U34.6 (P0_2)
/RF_ch3/C0.5_TX: U28.24 (C0.5), U34.15 (P1_2)
/RF_ch3/C0.25_RX: U31.1 (C0.25), U34.5 (P0_1)
/RF_ch3/C0.25_TX: U28.1 (C0.25), U34.14 (P1_1)
/RF_ch3/C1_RX: U31.23 (C1), U34.7 (P0_3)
/RF_ch3/C1_TX: U28.23 (C1), U34.16 (P1_3)
/RF_ch3/C2_RX: U31.22 (C2), U34.8 (P0_4)
/RF_ch3/C2_TX: U28.22 (C2), U34.17 (P1_4)
/RF_ch3/C4_RX: U31.21 (C4), U34.9 (P0_5)
/RF_ch3/C4_TX: U28.21 (C4), U34.18 (P1_5)
/RF_ch3/C8_RX: U31.20 (C8), U34.10 (P0_6)
/RF_ch3/C8_TX: U28.20 (C8), U34.19 (P1_6)
/RF_ch3/C16_RX: U31.19 (C16), U34.11 (P0_7)
/RF_ch3/C16_TX: U28.19 (C16), U34.20 (P1_7)
/RF_ch3/I2C_SCL_ATTN: U34.22 (SCL); also elsewhere on the board
/RF_ch3/I2C_SDA_ATTN: U34.23 (SDA); also elsewhere on the board
/RF_ch3/LE_RX: U31.16 (LE), U34.4 (P0_0)
/RF_ch3/LE_TX: U28.16 (LE), U34.13 (P1_0)
/RF_ch3/RX_FILTER_OUT: C108.1, T6.1
/RF_ch3/RX_IN: C86.2, U29.3 (RF1)
/RF_ch3/TX_OUT: C87.2, U29.1 (RF2)
/RF_ch3/~RX~_TX_SW: U29.6 (A); also elsewhere on the board
GND: C63.2, C64.2, C65.2, C68.2, C69.2, C70.2, C71.2, C72.2, C81.2, C85.2, C89.2, C90.2, C91.2, C94.2, C95.2, C96.2, C97.2, C98.2, C107.2, C111.2, C115.2, C116.2, C117.2, C120.2, C121.2, C122.2, C123.2, C124.2, C133.2, C137.2, F6.2 (GND), F6.4 (GND), F7.2 (GND), F7.4 (GND), F8.2 (GND), F8.4 (GND), F9.2 (GND), F9.4 (GND), F10.2 (GND), F10.4 (GND), F11.2 (GND), F11.4 (GND), F12.2 (GND), F12.4 (GND), F13.2 (GND), F13.4 (GND), F14.2 (GND), F14.4 (GND), F15.2 (GND), F15.4 (GND), F16.2 (GND), F16.4 (GND), F17.2 (GND), F17.4 (GND), J8.1, J9.1, J10.1, J11.1, J12.1, J13.1, J14.1, J15.1, J16.1, J17.1, J18.1, J19.1, J20.1, J21.1, J22.1, T3.2, T3.3, T3.4, T4.2, T4.3, T4.4, T5.2, T5.3, T5.4, T6.2, T6.3, T6.4, T7.2, T7.3, T7.4, T8.2, T8.3, T8.4, U20.3 (~P~/S), U20.4 (GND), U20.6 (GND), U20.7 (GND), U20.8 (GND), U20.9 (GND), U20.10 (GND), U20.11 (GND), U20.12 (GND), U20.13 (GND), U20.15 (GND), U20.17 (CLK), U20.18 (SI), U21.2 (GND), U23.3 (~P~/S), U23.4 (GND), U23.6 (GND), U23.7 (GND), U23.8 (GND), U23.9 (GND), U23.10 (GND), U23.11 (GND), U23.12 (GND), U23.13 (GND), U23.15 (GND), U23.17 (CLK), U23.18 (SI), U24.2 (GND), U25.2 (GND), U26.12 (VSS), U26.21 (ADDR), U28.3 (~P~/S), U28.4 (GND), U28.6 (GND), U28.7 (GND), U28.8 (GND), U28.9 (GND), U28.10 (GND), U28.11 (GND), U28.12 (GND), U28.13 (GND), U28.15 (GND), U28.17 (CLK), U28.18 (SI), U29.2 (GND), U31.3 (~P~/S), U31.4 (GND), U31.6 (GND), U31.7 (GND), U31.8 (GND), U31.9 (GND), U31.10 (GND), U31.11 (GND), U31.12 (GND), U31.13 (GND), U31.15 (GND), U31.17 (CLK), U31.18 (SI), U32.2 (GND), U33.2 (GND), U34.12 (VSS), U34.21 (ADDR), U36.3 (~P~/S), U36.4 (GND), U36.6 (GND), U36.7 (GND), U36.8 (GND), U36.9 (GND), U36.10 (GND), U36.11 (GND), U36.12 (GND), U36.13 (GND), U36.15 (GND), U36.17 (CLK), U36.18 (SI), U37.2 (GND), U39.3 (~P~/S), U39.4 (GND), U39.6 (GND), U39.7 (GND), U39.8 (GND), U39.9 (GND), U39.10 (GND), U39.11 (GND), U39.12 (GND), U39.13 (GND), U39.15 (GND), U39.17 (CLK), U39.18 (SI), U40.2 (GND), U41.2 (GND), U42.12 (VSS), U42.21 (ADDR); also elsewhere on the board
unnamed 162: C60.1; also elsewhere on the board
unnamed: C61.1, U20.14 (RF2)
unnamed: C62.1, U21.5 (RFC)
unnamed: C62.2, J8.2
unnamed: C66.1, U23.5 (RF1)
unnamed 167: C66.2, L5.2; also elsewhere on the board
unnamed 168: C67.1, L6.2; also elsewhere on the board
unnamed: C67.2, U20.5 (RF1)
unnamed: C73.1, F6.3 (RF_OUT)
unnamed 171: C73.2; also elsewhere on the board
unnamed: C74.1, U24.5 (RFC)
unnamed: C74.2, U23.14 (RF2)
unnamed: C75.1, F8.1 (RF_IN)
unnamed: C75.2, U24.1 (RF2)
unnamed: C76.1, F7.1 (RF_IN)
unnamed: C76.2, U24.3 (RF1)
unnamed: C77.1, J9.2
unnamed: C77.2, T3.6
unnamed: C78.1, J10.2
unnamed: C78.2, T3.5
unnamed: C79.1, U25.3 (RF1)
unnamed: C79.2, F8.3 (RF_OUT)
unnamed: C80.1, U25.1 (RF2)
unnamed: C80.2, F9.3 (RF_OUT)
unnamed: C82.2, U25.5 (RFC)
unnamed: C83.1, J11.2
unnamed: C83.2, T4.6
unnamed: C84.1, J12.2
unnamed: C84.2, T4.5
unnamed 191: C86.1; also elsewhere on the board
unnamed: C87.1, U28.14 (RF2)
unnamed: C88.1, U29.5 (RFC)
unnamed: C88.2, J13.2
unnamed: C92.1, U31.5 (RF1)
unnamed 196: C92.2, L7.2; also elsewhere on the board
unnamed 197: C93.1, L8.2; also elsewhere on the board
unnamed: C93.2, U28.5 (RF1)
unnamed: C99.1, F10.3 (RF_OUT)
unnamed 200: C99.2; also elsewhere on the board
unnamed: C100.1, U32.5 (RFC)
unnamed: C100.2, U31.14 (RF2)
unnamed: C101.1, F12.1 (RF_IN)
unnamed: C101.2, U32.1 (RF2)
unnamed: C102.1, F11.1 (RF_IN)
unnamed: C102.2, U32.3 (RF1)
unnamed: C103.1, J14.2
unnamed: C103.2, T5.6
unnamed: C104.1, J15.2
unnamed: C104.2, T5.5
unnamed: C105.1, U33.3 (RF1)
unnamed: C105.2, F12.3 (RF_OUT)
unnamed: C106.1, U33.1 (RF2)
unnamed: C106.2, F13.3 (RF_OUT)
unnamed: C108.2, U33.5 (RFC)
unnamed: C109.1, J16.2
unnamed: C109.2, T6.6
unnamed: C110.1, J17.2
unnamed: C110.2, T6.5
unnamed 220: C112.1; also elsewhere on the board
unnamed: C113.1, U36.14 (RF2)
unnamed: C114.1, U37.5 (RFC)
unnamed: C114.2, J18.2
unnamed: C118.1, U39.5 (RF1)
unnamed 225: C118.2, L9.2; also elsewhere on the board
unnamed 226: C119.1, L10.2; also elsewhere on the board
unnamed: C119.2, U36.5 (RF1)
unnamed: C125.1, F14.3 (RF_OUT)
unnamed 229: C125.2; also elsewhere on the board
unnamed: C126.1, U40.5 (RFC)
unnamed: C126.2, U39.14 (RF2)
unnamed: C127.1, F16.1 (RF_IN)
unnamed: C127.2, U40.1 (RF2)
unnamed: C128.1, F15.1 (RF_IN)
unnamed: C128.2, U40.3 (RF1)
unnamed: C129.1, J19.2
unnamed: C129.2, T7.6
unnamed: C130.1, J20.2
unnamed: C130.2, T7.5
unnamed: C131.1, U41.3 (RF1)
unnamed: C131.2, F16.3 (RF_OUT)
unnamed: C132.1, U41.1 (RF2)
unnamed: C132.2, F17.3 (RF_OUT)
unnamed: C134.2, U41.5 (RFC)
unnamed: C135.1, J21.2
unnamed: C135.2, T8.6
unnamed: C136.1, J22.2
unnamed: C136.2, T8.5
unnamed: F6.1 (RF_IN), T3.1
unnamed: F7.3 (RF_OUT), F9.1 (RF_IN)
unnamed: F10.1 (RF_IN), T5.1
unnamed: F11.3 (RF_OUT), F13.1 (RF_IN)
unnamed: F14.1 (RF_IN), T7.1
unnamed: F15.3 (RF_OUT), F17.1 (RF_IN)
unnamed: R27.2, U26.3 (~RESET)
unnamed: R28.2, U34.3 (~RESET)

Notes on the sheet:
TX Path
TX Differential Input
LPF Passband (-1dB): 0 - 3.6 GHz
Gain: 22.2 dB BW: 30 - 6000 MHz P1dB: 21.0 dBm @ 900 MHz OIP3: 40.0 dBm @ 900 MHz
DC Bias Max Power Draw: 124 mA
RFC-RF1: A=0,B=1 RFC-RF2: A=1,B=0 P1dB = 39 dBm t_switch = 30 ns
ADDR: 0x20
2nd Nyquist Zone Filter Composite Bandpass Filter: 2.3 - 3.6 GHz LPF Passband (-1dB): 0 - 3.6 GHz HPF Passband (-1dB): > 2.3 GHz
1st Nyquist Zone Filter LPF Passband (-1dB): 0 - 2.14 GHz
RX Differential Output
RX Path
RX/TX SMA
I2C GPIO Expander
7-bit (0.25dB) DSA Attn: 0 - 31.75 dB BW: 9 kHz - 6 GHz

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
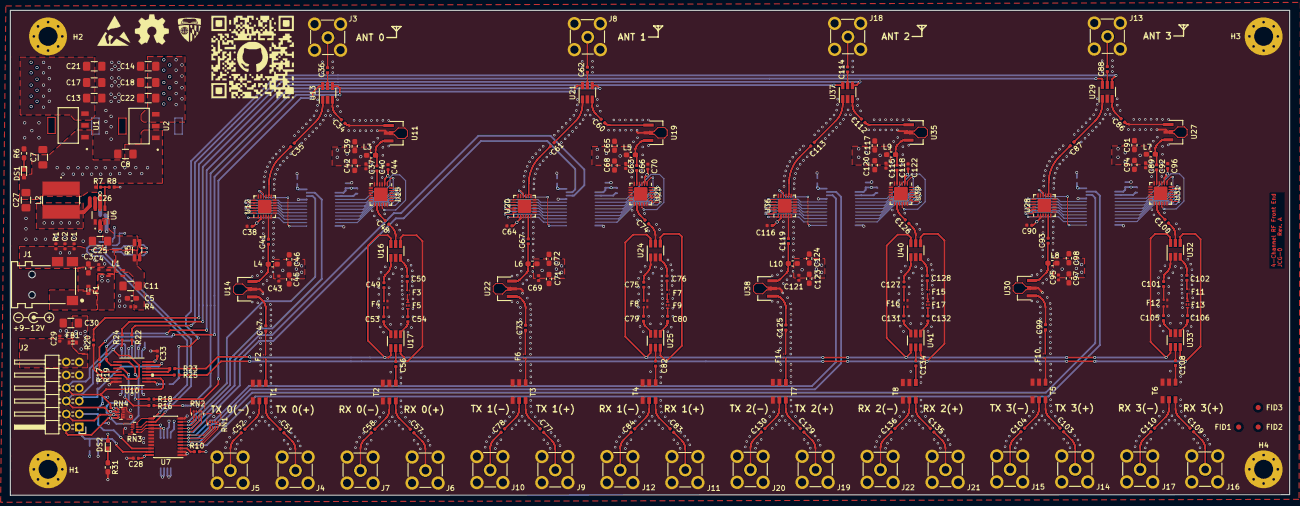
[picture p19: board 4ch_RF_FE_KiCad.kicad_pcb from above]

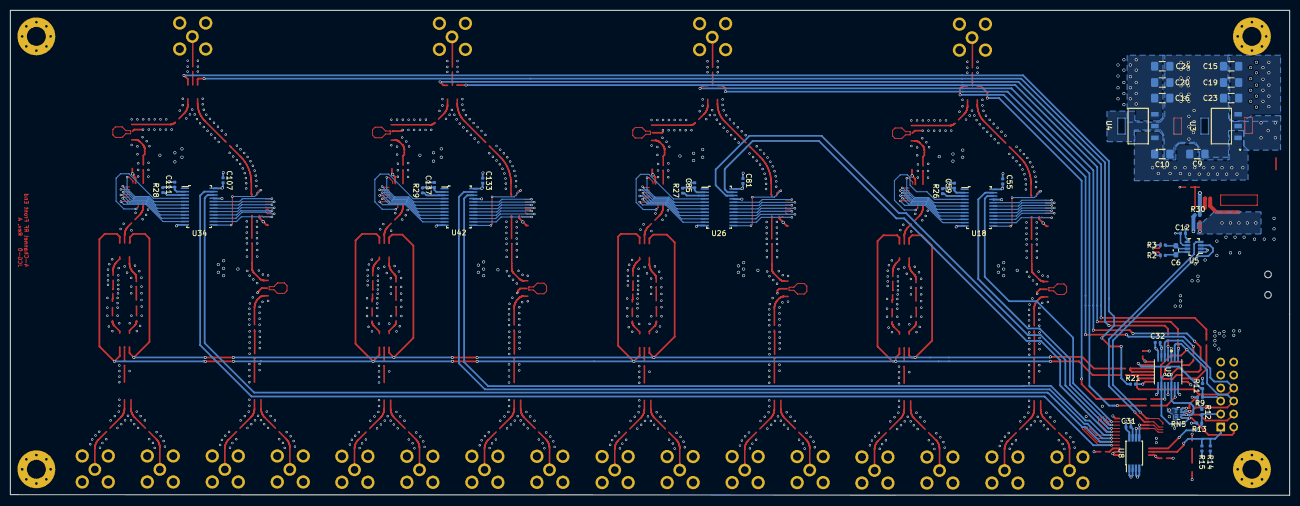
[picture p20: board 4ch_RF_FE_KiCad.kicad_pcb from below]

Board: 4 copper layers, 249.9 x 94.7 mm, 282 parts (44 on the bottom side), 267 nets.

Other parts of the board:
U19, U22, U27, U30, U35, U38: RK_3; ADL5611ARKZ-R7

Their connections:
GND: U19.2, U22.2, U27.2, U30.2, U35.2, U38.2; also elsewhere on the board
unnamed 162: U19.1; also elsewhere on the board
unnamed 167: U19.3; also elsewhere on the board
unnamed 168: U22.3; also elsewhere on the board
unnamed 171: U22.1; also elsewhere on the board
unnamed 191: U27.1; also elsewhere on the board
unnamed 196: U27.3; also elsewhere on the board
unnamed 197: U30.3; also elsewhere on the board
unnamed 200: U30.1; also elsewhere on the board
unnamed 220: U35.1; also elsewhere on the board
unnamed 225: U35.3; also elsewhere on the board
unnamed 226: U38.3; also elsewhere on the board
unnamed 229: U38.1; also elsewhere on the board

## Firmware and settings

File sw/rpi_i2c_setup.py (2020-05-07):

#!/usr/bin/python
#
# Python Code for Raspberry Pi I2C Setup of 4-Ch RF Front End
#   Tested on Raspberry Pi 3 Model B using dedicated GPIO I2C pins 3 & 5
#   and +3.3V power (note << 50mA current required so does not violate
#   Raspberry Pi power specifications), and all other I/O are +3.3V push-pull
#   logic. It's also assumed that I2C is configured for the kernel
#   (`raspi-config` and `i2c-tools`)
#
# Pinout (from top-right GPIO header, pins on left side):
#                         +3V3 ---( 1) ( 2)---
#                      I2C SDA ---( 3) ( 4)---
#                      I2C SCL ---( 5) ( 6)---
#                              ---( 7) ( 8)---
#                          GND ---( 9) (10)---
#         ~RX/TX CH0 [GPIO 17] ---(11) (12)---
#         ~RX/TX CH1 [GPIO 27] ---(13) (14)---
#   ~1st/2nd Nyq Sel [GPIO 22] ---(15) (16)---
#
#   * For more pinout details, see https://pinout.xyz/pinout/i2c
#
# Python Libs used:
#   - [gpiozero](https://gpiozero.readthedocs.io/en/stable/)
#   - SMBus I2C (python-smbus package)
#
# ToDo:
#   - Current attenuation setting logic does not account for possible
#     0.25/0.5 dB resolution
#

import smbus
import math
from time import sleep
from gpiozero import LED

### Device constants (addresses are 7-bit)
ADDR_I2C_MUX        = 0x70  # PCA9548APW 8-Ch MUX [U7]
ADDR_I2C_EEPROM     = 0x50  # M24C02-FDW 2kb EEPROM [U8] (Channel 5)
ADDR_I2C_INA219     = 0x40  # INA219 High-Side power monitor [U5] (Channel 4)
ADDR_I2C_GPIO       = 0x20  # PCAL6416APW GPIO Expander (Channels 0-3)
# I2C MUX Channel Definitions
MUX_CH_RF_CH3_ATTN  = 0
MUX_CH_RF_CH2_ATTN  = 1
MUX_CH_RF_CH1_ATTN  = 2
MUX_CH_RF_CH0_ATTN  = 3
MUX_CH_INA219       = 4
MUX_CH_EEPROM       = 5

# PCAL6416 I2C GPIO Port Expander Register Addresses
GPIO_REG_INPUT_P0   = 0x00 # incoming logic level (P0.7-0)
GPIO_REG_INPUT_P1   = 0x01 # incoming logic level (P1.7-0)
GPIO_REG_OUTPUT_P0  = 0x02 # outgoing logic level (P0.7-0)
GPIO_REG_OUTPUT_P1  = 0x03 # outgoing logic level (P1.7-0)
GPIO_REG_INVERT_P0  = 0x04 # invert polarity of P0.7-0
GPIO_REG_INVERT_P1  = 0x05 # invert polarity of P1.7-0
GPIO_REG_DIR_P0     = 0x06 # [0] = output enabled, [1] = high-Z input (P0.7-0)
GPIO_REG_DIR_P1     = 0x07 # [0] = output enabled, [1] = high-Z input (P1.7-0)
GPIO_REG_DRIVE_P0a  = 0x40 # P0.3-0 output drive strength
GPIO_REG_DRIVE_P0b  = 0x41 # P0.7-4 output drive strength
GPIO_REG_DRIVE_P1a  = 0x42 # P1.3-0 output drive strength
GPIO_REG_DRIVE_P1b  = 0x43 # P1.7-4 output drive strength
GPIO_REG_LATCH_P0   = 0x44 # Enable latch I/O (P0.7-0)
GPIO_REG_LATCH_P1   = 0x45 # Enable latch I/O (P1.7-0)
GPIO_REG_PULL_EN_P0 = 0x46 # Enable pull-up/down (P0.7-0)
GPIO_REG_PULL_EN_P1 = 0x47 # Enable pull-up/down (P1.7-0)
GPIO_REG_PUD_P0     = 0x48 # [0] pull-down, [1] pull-up (P0.7-0)
GPIO_REG_PUD_P1     = 0x49 # [0] pull-down, [1] pull-up (P1.7-0)
GPIO_REG_INTM_P0    = 0x4A # [0] enable interrupt mask (P0.7-0)
GPIO_REG_INTM_P1    = 0x4B # [0] enable interrupt mask (P1.7-0)
GPIO_REG_INTS_P0    = 0x4C # RO interrupt status (P0.7-0)
GPIO_REG_INTS_P1    = 0x4D # RO interrupt status (P1.7-0)
GPIO_PORT_CONFIG    = 0x4F # set I/O as [0] push-pull, [1] open-drain

# Bus/GPIO class initializations
bus = smbus.SMBus(1) # target /dev/i2c-1 from ARM BCM SoC
ch0RxTxSw  = LED(17)
ch1RxTxSw  = LED(27)
nyqBandSel = LED(22)

# configure GPIO Expander for currently selected I2C Channel
def configGpioExp():
	print('  Setting ports to output direction...')
	# setting Port 0_x & 1_x to push-pull outputs
	bus.write_byte_data(ADDR_I2C_GPIO, GPIO_PORT_CONFIG, 0x00)
	bus.write_byte_data(ADDR_I2C_GPIO, GPIO_REG_DIR_P0, 0x00)
	bus.write_byte_data(ADDR_I2C_GPIO, GPIO_REG_DIR_P1, 0x00)
	# set Port outputs low to start with
	bus.write_byte_data(ADDR_I2C_GPIO, GPIO_REG_OUTPUT_P0, 0x00)
	bus.write_byte_data(ADDR_I2C_GPIO, GPIO_REG_OUTPUT_P1, 0x00)
	print('  Current P0 Output: ' + hex(bus.read_byte_data(ADDR_I2C_GPIO, GPIO_REG_OUTPUT_P0)))
	print('  Current P1 Output: ' + hex(bus.read_byte_data(ADDR_I2C_GPIO, GPIO_REG_OUTPUT_P1)))


# I2C MUX channel enabled simply by left shifting enable
print('Configuring GPIO Expander for RF Channel 0...')
bus.write_byte(ADDR_I2C_MUX, 1 << MUX_CH_RF_CH0_ATTN)
# Useful debug for PCA switch:
#print('I2C Channel %2d enabled' %math.log(bus.read_byte(ADDR_I2C_MUX), 2))
configGpioExp()
sleep(0.1)
print('Configuring GPIO Expander for RF Channel 1...')
bus.write_byte(ADDR_I2C_MUX, 1 << MUX_CH_RF_CH1_ATTN)
configGpioExp()

print('Setting filter banks to 1st Nyquist path...')
nyqBandSel.off() # [0] = 1st Nyquist, [1] = 2nd Nyquist
print('Setting RF Channel 0 Switch: RX')
ch0RxTxSw.off()  # [0] = RX, [1] = TX
print('Setting RF Channel 1 Switch: TX')
ch1RxTxSw.on()   # [0] = RX, [1] = TX

usrInput = ''
while usrInput != 'quit':
	usrInput = raw_input(">>> Set Channel Selection [0|1] (or enter 'quit'): ")
	if usrInput != 'quit':
		if usrInput == '0':
			bus.write_byte(ADDR_I2C_MUX, 1 << MUX_CH_RF_CH0_ATTN)
		elif usrInput == '1':
			bus.write_byte(ADDR_I2C_MUX, 1 << MUX_CH_RF_CH1_ATTN)
		else:
			print('Unknown channel number...')
			continue
	else:
		break
	usrInput = raw_input(">>> Select Path [RX|TX]: ")
	if usrInput == 'RX':
		usrInput = raw_input(">>> Set attenuation (0-31dB): ")
		atten = int(usrInput)
		if (atten < 0) or (atten > 31):
			print('Attenuation value not between 0 - 31 dB!')
			continue
		# shift to create atten value, latch then unlatch value
		bus.write_byte_data(ADDR_I2C_GPIO, GPIO_REG_OUTPUT_P0, atten << 3)
		sleep(0.1)
		bus.write_byte_data(ADDR_I2C_GPIO, GPIO_REG_OUTPUT_P0, (atten << 3)|1)
		# debug readback of latched attenuation value
		print('  Port Setting: ' + hex(bus.read_byte_data(ADDR_I2C_GPIO, GPIO_REG_OUTPUT_P0)))
		sleep(0.1)
		bus.write_byte_data(ADDR_I2C_GPIO, GPIO_REG_OUTPUT_P0, atten << 3)
		print('DONE')
	elif usrInput == 'TX':
		usrInput = raw_input(">>> Set attenuation (0-31dB): ")
		atten = int(usrInput)
		if (atten < 0) or (atten > 31):
			print('Attenuation value not between 0 - 31 dB!')
			continue
		# shift to create atten value, latch then unlatch value
		bus.write_byte_data(ADDR_I2C_GPIO, GPIO_REG_OUTPUT_P1, atten << 3)
		sleep(0.1)
		bus.write_byte_data(ADDR_I2C_GPIO, GPIO_REG_OUTPUT_P1, (atten << 3)|1)
		# debug readback of latched attenuation value
		print('  Port Setting: ' + hex(bus.read_byte_data(ADDR_I2C_GPIO, GPIO_REG_OUTPUT_P1)))
		sleep(0.1)
		bus.write_byte_data(ADDR_I2C_GPIO, GPIO_REG_OUTPUT_P1, atten << 3)
		print('DONE')
	else:
		print('Unknown path selection...')

print('Exiting...')

# For 2kb EEPROM, address/register ranges from 0x00 - 0xFF
# EEPROM can store calibration/attenuation values for each channel
#bus.write_byte(ADDR_I2C_MUX, 1 << MUX_CH_EEPROM)
#print('I2C Channel %2d enabled' %math.log(bus.read_byte(ADDR_I2C_MUX), 2))
#for i in range(0, 32):
#	print('EEPROM Addr ' + hex(i) + ': ' + hex(bus.read_byte_data(ADDR_I2C_EEPROM, i)))

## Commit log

2020-03-03 (+) docs & KiCad design
    [4ch_RF_FE_KiCad.kicad_pcb, 4ch_RF_FE_KiCad.sch, RF_channel.sch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]
2020-03-08 initial completion of schematic capture
    [4ch_RF_FE_KiCad.kicad_pcb, 4ch_RF_FE_KiCad.sch, PMOD_DIO.sch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]
2020-03-11 (+) starting layout
    [4ch_RF_FE_KiCad.kicad_pcb, 4ch_RF_FE_KiCad.sch, PMOD_DIO.sch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]
2020-03-11 change footprint/schematic paths from absolute -> relative
2020-03-14 (+) power & DIO layout & impedance calcs
    [4ch_RF_FE_KiCad.kicad_pcb, PMOD_DIO.sch, RF_channel.sch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]
2020-03-17 RF layout
    [4ch_RF_FE_KiCad.kicad_pcb, 4ch_RF_FE_KiCad.sch, PMOD_DIO.sch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]
2020-03-19 more optimized RF layout, smaller overal layout
    [4ch_RF_FE_KiCad.kicad_pcb]
2020-03-20 final layout
    [4ch_RF_FE_KiCad.kicad_pcb, PMOD_DIO.sch]
2020-03-20 (+) final silkscreen changes
    [4ch_RF_FE_KiCad.kicad_pcb]
2020-03-20 (+) schematic output
2020-03-21 (+) QR code -> shipped to OSH Park
    [4ch_RF_FE_KiCad.kicad_pcb]
2020-04-02 bom tool
2020-04-07 (+) BOM CXV
    [4ch_RF_FE_KiCad_bom_A.csv]
2020-04-16 (+) Device tree bindings for digital components
2020-04-16 INA219 DNP in device tree
2020-05-02 (+) shottky diode for testing
2020-05-07 (+) I2C setup/control script for Raspberry Pi's
